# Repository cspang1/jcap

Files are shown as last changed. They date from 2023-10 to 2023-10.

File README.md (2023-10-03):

<h1 align="center">JCAP</h1>

<p align="center"><b>Check out the <a href="https://github.com/cspang1/JCAP/wiki">Project Wiki</a> for the development log</b></p> 
<p align="center"><b>A custom game resource creation software suite <a href="https://github.com/cspang1/jide">is being developed</a> for the inaugural JCAP release!</b></p> 

<hr>

<p>JCAP is a project with the goal of developing a <a href="https://www.mikesarcade.com/cgi-bin/spies.cgi?action=url&type=pinout&page=Jamma.html">JAMMA arcade standard</a> compatible game board using the <a href="https://www.parallax.com/product/p8x32a-q44">Parallax Propeller 1 (P8X32A) microcontroller</a> upon which a user can implement their own custom arcade game, either from scratch or by using the library of graphics, sound, input, and other drivers developed under the project. Ultimately, the project will provide all of the following in such a way that a user has everything they need to implement their own arcade game and have a PCB printed to build it on:</p>

<ul>
  <li>VGA video driver</li>
  <li>Sprite/tile based graphics driver</li>
  <li>PWM sound driver</li>
  <li>Serialized input driver</li>
  <li>Game engine</li>
  <li>Board schematic</li>
  <li>PCB .gerber files</li>
  <li>PCB BOM</li>
</ul>

<p align="center">JCAP Dev PCB</p>

<h1 align="center">Contribution Guidelines</h1>
<p>On the off chance anyone is interested in contributing to JCAP, there are some basic standards which should be ahered to:</p>

<ol>
  <li>Document everything! For code documentation, use existing code (e.g. Dev/Input/Software/input.spin) as an example. PASM should be documented somewhat anal-retentively, line-by-line, with block comments for routines and subroutines. Header comments should follow the same standard established by existing code as well.</li>
  <li>Any discovered problems/concerns/features that you won't be addressing with your current commit need to have an issue created and assigned to the appropriate person(s), tag, milestone, and project. This eliminates the risk of development amnesia. Additionally, when a commit has satisfied an issue, the commit hash should be referenced in the closing comment of the issue.</li>
  <li>Commit messages need to at a minimum broadly describe each change made to the repository. Whether it's fixing a bug, adding a feature, adding a new datasheet, or updating some indentation, one should be able to read the commit message and understand immediately what's been done to the repo.</li>
  <li>Any documents (manuals, datasheets, tutorials) which are critical to your contributions should be placed in their appropriate subdirectories in /Docs. For similarly important generic links, place them in "Useful Links.txt" in /Docs.</li>
</ol>

<p>Pull requests that don't follow these guidelines will be rejected until corrections have been made. While this all may seem like an over-processed waste of time, an auxiliary goal for JCAP is to create a project which maintains the highest possible standards to prevent headache down the road and belay confusion to anyone on the outside looking in.</p>

<h1 align="center">Current Contributors</h1>
<p>The following individuals have contributed to JCAP:</p>

<ul>
  <li>Connor Spangler (cspang1)</li>
  <li>Marko Lukat (konimaru)</li>
</ul>

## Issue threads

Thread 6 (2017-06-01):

Improve 1 microsecond wait subroutine accuracy

cspang1, 2017-06-01:
Currently the wait subroutine exhibits ~.1 us (10%) error.

cspang1, 2017-06-01:
Made unecessary by Issue #9

Closed 2017-06-01.

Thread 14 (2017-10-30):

Perform incrementally misdirected memory access to narrow down tile/color palette VGA issue

cspang1, 2017-10-30:
VGA video dropping entirely with current wip/video/vga vga.spin code as of commit bca37a7fc0f61dbfe6b39d387e2ab001ae3f2507.

Start by trying to directly access color palette and go from there.

cspang1, 2017-10-30:
Issues fixed with commit 9e7ead5c21c01ada62f194a305cbc3deedda6113. Issue was **par** passed to cog is the address of the address of the start of the tile/color resources. So needed to perform _rdlong_ to retrieve the actual addresses of the resources.

Closed 2017-10-30.

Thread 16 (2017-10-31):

Implement Sprite rendering into VGA driver

cspang1, 2017-10-31:
Sprite rendering feature necessary for sprite-based graphics.

cspang1, 2018-01-29:
Being addressed by issue #32

Closed 2018-01-29.

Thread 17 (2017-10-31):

Refactoring of VGA engine set-up for VGA video driver

cspang1, 2017-10-31:
Configuration values are currently hard-coded into VGA driver; need to calculate these values in Hub's Spin and/or Cog's PASM code.

cspang1, 2017-11-02:
Satisfied by commit b4942502ab091ed00d26ba111a279e9dc56a0368

Closed 2017-11-02.

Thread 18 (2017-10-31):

Add content to Propeller 1 wiki page

cspang1, 2017-10-31:
Replace placeholder text with information on Propeller 1 microcontroller, how it works, etc.

Closed 2017-11-02.

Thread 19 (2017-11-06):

Refactor VGA driver code to iteratively assign internal registers from main RAM

cspang1, 2017-11-06:
Currently, all registers in the driver cog which need to be populated with values calculated in the hub are done so one at a time in what's essentially an unrolled loop. Need to determine if there is a way to set them all in a single tight loop.

konimaru, 2017-11-06:
_It's a shame really. Those things have been figured out a long time ago ..._

Check out [this link](http://forums.parallax.com/discussion/comment/1108886/#Comment_1108886), it's a generic loop transferring **a long per hub cycle** in either direction. There is also a counter based version pre-dating this one which - while OK for me - wasn't generally accepted (and sometimes you don't have a spare counter). Anyway, use (one of) them if you want/need speed ...

konimaru, 2017-11-06:
I apologize for the mess Parallax made during forum transition(s) which is the reason I stopped participating.

cspang1, 2017-11-06:
@konimaru Thanks, looks like just the thing I need. Hadn't even gotten around to Googling for a solution yet so thanks for saving me a step! Only thing is that the procedure looks almost as nasty (instruction-wise and visually) as explicitly setting variables, no matter how you do it.

konimaru, 2017-11-06:
Your call. I - obviously - use this in most of my drivers (where applicable). And the setup is only required once.

cspang1, 2017-11-06:
@konimaru True story! I'm definitely riding the assembly-timing learning curve into outer space. I'm actually going to have to do a refactor of my VGA driver to populate a line buffer during the visible porch/sync regions, instead of racing to grab a new tile every time I need it. As-is the driver works fine up to 15 horizontal 16x16 tiles, or 16 horizontal 8x8 tiles. Past that, de-sync.

cspang1, 2017-11-07:
Satisfied by commit a2ff0f2167f0a29744ab3d61e357886df1cfc68d

konimaru, 2017-11-07:
For the record, I just realised you only wanted a one-off load not something repeating (where speed might be important).

cspang1, 2017-11-07:
@konimaru no problem! There's an entirely realistic chance the driver will change in the future to make that necessary, and being aware of the execution-time conscious approach is useful.

Closed 2017-11-07.

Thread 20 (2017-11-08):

Investigate multi-cog vs dedicated PPU video generation approach

cspang1, 2017-11-08:
Current driver has to render faster than it can load the next tile/color at high tile dimensions, and adding the sprite rendering feature will only exacerbate this. The benefits of spreading the rendering of each line over multiple cogs vs having a dedicated PPU with screen buffer need to be investigated.

cspang1, 2017-11-10:
@konimaru I'm definitely interested in discussing what you discuss in this thread if you have the time: http://forums.parallax.com/discussion/126874

konimaru, 2017-11-10:
Ah, that one. I felt a bit odd replying to myself :) Anyway, what are you after?

cspang1, 2017-11-10:
I guess first off, what's the final "verdict" you reached on fully deterministic and synced **waitvid** timing? I see you go through quite a few iterations of solutions, and in your final version you freeze the video hardware before changing **vscl**. Does that have to be done for every change of **vscl** (for example changing for vertical blanking lines and HSync) or just initially?

konimaru, 2017-11-10:
Let me ponder this for a while. This is really **old** stuff and these days I simply _use_ it.

cspang1, 2017-11-10:
@konimaru Haha understood, no problem! I'm working on getting the general structure of this refactor together right now, so no rush!

cspang1, 2017-11-15:
@konimaru I've managed to implement a cog sync method (based on your and Linus's legwork) that's at least as good as it needs to be. I'm not going down the rabbit hole of WHOP methodology at this stage, and likely won't in the future, as the resolutions I'm working with don't require that kind of time-shaving and code obfuscation. I'm still interested in the odd behavior exhibited by the video generation hardware.

As far as this issue goes, I've chosen to go with a multi-cog approach over one requiring a dedicated PPU. My graphics demands simply aren't high enough to warrant a PPU, and at this point I've managed to wrap my head around the multi-cog approach enough to implement it.

cspang1, 2018-01-29:
This paradigm ended up being chosen as the way forward.

Closed 2017-11-15.

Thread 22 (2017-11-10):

Refactor VGA driver to perform interlacing

cspang1, 2017-11-10:
Current line of effort on Issue #20 involves interlacing scanlines via n separate cogs, where each cog renders and displays alternating scanlines e.g. 4 cogs render every fourth line.

cspang1, 2017-11-22:
Satisfied by commit 9f4956a

@konimaru - [success!](https://www.youtube.com/watch?v=sTBAv1NuYT8)

Closed 2017-11-22.

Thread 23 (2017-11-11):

Graphics driver can not be started again after being stopped

cspang1, 2017-11-11:
Calling graphics.start after graphics.stop (or calling graphics.start while driver is already running) results in no video.

konimaru, 2017-11-13:
What is this driver you speak of? The only [**graphics.spin**](https://github.com/cspang1/JCAP/tree/4a9e0d7ffa2518b786a3eae2e0d4fc0a2039d16b/Dev/Game/Software) I could find doesn't even have a **stop** method. And simply calling **start** on that one again will also start another VGA driver underneath (with expected results).

cspang1, 2017-11-13:
@konimaru it's on the feature/video/vga/multicog branch: https://github.com/cspang1/JCAP/tree/feat/video/vga/multicog/Dev/Game/Software

konimaru, 2017-11-13:
This should do the trick:
```
PUB start(graphics_addr_base) : vidstatus | nCogs,i                             ' Function to start VGA driver with pointer to Main RAM variables
    stop                                                                        ' Stop running driver
    repeat i from 0 to numCogs-1                                                ' Loop through cogs
      ifnot cog_[i] := cognew(@vga, graphics_addr_base) + 1                     ' Initialize cog running "vga" routine with reference to start of variable registers
        stop                                                                    ' Stop all cogs if insufficient number available
        abort FALSE                                                             ' Abort returning FALSE
    waitcnt($8000 + cnt)                                                        ' Wait for cogs to finish initializing
    return TRUE                                                                 ' Return TRUE                                        
```
Note the extra **stop** call. This makes sure consecutive **start** calls don't attempt to start thousands of drivers. That said, this wouldn't explain the not-working **stop/start** sequence.

cspang1, 2017-11-13:
@konimaru That definitely did the trick, because in my test code for stopping and starting the driver I don't check if it's already running or not and the input to start/stop is constant, so it just spams start or stop...

`  started := false

  repeat
    if (control_state & 8) AND started
      started := false
      graphics.stop
    elseif (control_state & 4) AND !started
      started := true
      graphics.start`

I code good.

Satisfied by commit 713ed567d48169d914dfebaab7385abe59c118cb

konimaru, 2017-11-14:
Out of curiosity, why did you put this logic into to the application? Isn't the driver itself better suited for this (i.e. keeping state info)?

cspang1, 2017-11-14:
@konimaru Yes it definitely is! I was just testing to make sure the start and stop routines worked, and the easiest way at the time was to control them with button presses. I forsee no real reason I should ever have to stop or restart the video driver unless I implement some sort of software reset for the whole system, so just novelty mixed with making sure everything is tested instead of assumed-working.

konimaru, 2017-11-14:
OK, I thought this is for deployment. Personally I only implement **init** methods. No-one is stopping things anyway so there :)

cspang1, 2017-11-14:
@konimaru That's definitely a cleaner design paradigm haha.

Just a heads up, any branch that's preceded by "wip" is baseline "work in progress" (standard dev, such as for wip/video/vga or wip/video/sound), "feat" is "feature" (a unique dev aspect, such as feat/video/vga/multicog which is focused on refactoring my single-cog driver into a synchronized parallelized one). Other prefixes may be used for things like hotfixes etc. Nothing is merged with master until development on it is considered "complete" (for example, the wip/input branch was merged a while back because I considered the 74HC165 interfacing complete).The idea is that the only production/deployment code will be in master, and everything else is dev.

cspang1, 2017-11-17:
Starting/stopping driver exhibiting strange behavior again.

cspang1, 2017-11-27:
Stopping then starting the driver results in apparently valid sync waveforms, but not video.

cspang1, 2018-01-22:
Made unecessary by dual-Propeller development.

Closed 2018-01-22.

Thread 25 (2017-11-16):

Increase delay between multicog VGA driver cog initializations

cspang1, 2017-11-16:
Currently cogs are launched too rapidly to allow time for the porch sizes to be changed. [Fix identified](https://github.com/cspang1/JCAP/commit/df0fe57e5db38a64c85252066908ad63cf9fe638#commitcomment-25661286) by @konimaru.

cspang1, 2017-11-17:
Satisfied by commit 041e99e710730ddc134a960add3e83da4521f186

Closed 2017-11-17.

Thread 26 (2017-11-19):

Parameterize size of VGA driver scanline buffer(s)

cspang1, 2017-11-19:
[Issue discussed here.](http://forums.parallax.com/discussion/167698/modifying-a-res-statement-before-cog-launch)

cspang1, 2018-01-22:
Made unecessary by dual-Propeller development.

Closed 2018-01-22.

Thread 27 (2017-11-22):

VGA driver tile and color retrieval refactor

konimaru, 2017-11-22:
While probably not terribly important right now I'd suggest a minor change to this:
```
        shl             ti,     tOffset         ' Multiply tile index by size of tile map
        add             ti,     tpbase          ' Increment tile index to correct line
        add             ti,     tpptr           ' Add tile palette pointer to tile index to specify row of tile to be displayed
rdtile  rdlong          tile,   ti              ' Read 16-pixel-wide tile from Main RAM
        shl             ci,     #2              ' Multiply color index by size of color palette
        add             ci,     cpbase          ' Increment color index to correct palette
        rdlong          colors, ci              ' Read tile from Main RAM
movp    mov             0-0,    tile            ' Store tile row to pixel buffer
movc    mov             0-0,    colors          ' Store color palette to color buffer
        add             movp,   incDest         ' Increment tile buffer pointer
        add             movc,   incDest         ' Increment color buffer pointer
```
Here **tile** and **colors** are loaded from hub _then_ transferred to a cog location (2 steps). This could easily be done in a single step e.g.
```
        shl             ti,     tOffset         ' Multiply tile index by size of tile map
        add             ti,     tpbase          ' Increment tile index to correct line
        add             ti,     tpptr           ' Add tile palette pointer to tile index to specify row of tile to be displayed
rdtile
movp    rdlong          0-0,    ti              ' Read 16-pixel-wide tile from Main RAM
        shl             ci,     #2              ' Multiply color index by size of color palette
        add             ci,     cpbase          ' Increment color index to correct palette
movc    rdlong          0-0,    ci              ' Read tile from Main RAM
        add             movp,   incDest         ' Increment tile buffer pointer
        add             movc,   incDest         ' Increment color buffer pointer
```

konimaru, 2017-11-22:
... and to bring this loop a bit (more) in sync with hub window slots:
```
line    rdbyte          ti,     tmptr           ' Read tile index of current map tile
        add             tmptr,  #1              ' Increment tile map pointer to color index
        shl             ti,     tOffset         ' Multiply tile index by size of tile map
        rdbyte          ci,     tmptr           ' Store color index of current map tile
        add             ti,     tpbase          ' Increment tile index to correct line
        add             ti,     tpptr           ' Add tile palette pointer to tile index to specify row of tile to be displayed
rdtile
movp    rdlong          0-0,    ti              ' Read 16-pixel-wide tile from Main RAM
        shl             ci,     #2              ' Multiply color index by size of color palette
        add             ci,     cpbase          ' Increment color index to correct palette
movc    rdlong          0-0,    ci              ' Read tile from Main RAM
        add             movp,   incDest         ' Increment tile buffer pointer
        add             movc,   incDest         ' Increment color buffer pointer
        add             tmptr,  #1              ' Increment tile map pointer to next tile in row
        djnz            tptr,   #line           ' Generate one scanline of data
```

cspang1, 2017-11-22:
@konimaru Great suggestions. A refactor of the tile/color loading to minimize and hub access sync the routine was definitely in order.

cspang1, 2017-11-22:
Satisfied by commit e3f658b90084b0c7b4d8ea538a7e07b9c4d766e0

Closed 2017-11-22.

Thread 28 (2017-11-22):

Refactor multicog VGA driver to re-utilize initialization code as buffer space

cspang1, 2017-11-22:
Chip's high-res VGA driver recycles initialization code to allocate space for the scanline buffer. With a max horizontal tile resolution of 40 tiles, the combined pixel and color buffers for four lines will be **40 * 4 * 2 = 320 longs**. With 496 longs per cog available for instructions and variables, this leaves **496 - 320 = 176 longs available for the VGA driver**. Re-utilizing initialization space, as well as general refactoring of the driver, should be adequate to fit everything.

konimaru, 2017-11-22:
176 longs aren't as much as you think :)

What is the timing like ATM? Could you potentially get away with only two scan lines which need buffering?

cspang1, 2017-11-22:
@konimaru That's the point I'm actually trying to highlight haha; 176 isn't that much space, so re-using initialization code space will help. Right now, the main driver code (sans initialization code) is ~134 longs, and that's without the sprite engine yet.

For 640 x 480 @ 60 Hz, the amount of time over 4 lines that the driver has available to populate the scanline buffer is ~127 microseconds. Best case scanario (all instructions take 4 cycles, so basically ignoring missed jumps and hub memory access) is I can execute 2,540 instructions during this time. Right now @ 40 tiles per scanline I'm at ~2,277 counting all instructions as 4 cycles; so honestly it's probably blowing it as is.

Going down to 2 lines per cog, I would have enough time between display periods to execute 1270... have to finish this in a bit

cspang1, 2017-11-22:
Going down to two lines per cog would rob me of two horizontal sync regions worth of buffer population time, so that's out since I'm already basically at capacity.

This is definitely an area of concern I'll have to address. The thing is though it's only an issue for 40 tile wide screens which is the highest I want to support (most games fall between 30 and 40). The next highest compatible width is 20 but that's honestly too low to make a respectable game from.

cspang1, 2017-11-22:
There are two possible branches to consider at this point:

1. I go from 2 cogs/4 lines each to 4 cogs/1 line each, which would essentially give me 3 entire scan lines worth of time to generate the data for only one (instead of attempting to leverage the horizontal sync areas of 4 lines to find time for 4 lines worth of data).

or...

2. I switch over to a method where there is no interlacing, there is only a cog dedicated to pulling in raw (i.e. already dereferenced from the tile map/palette and colored) video data from Main RAM which is populated by dedicated "render" cogs. This would result in essentially a "backwards" **waitvid**, where each long contains 4 8-bit pixels worth of data and I just print them sequentially. This means a LOT more **waitvids** per line, which means a much lower maximum horizontal video resolution of 256 pixels. Which, to be honest, isn't a deal-breaker as it's still a valid resolution displayable by VGA monitors AND it's actually closer to what classic arcade games displayed via CRT.

For now I'm going to keep working at the current paradigm and leverage some of Chip's high-res VGA driver tricks to see what I can squeeze into the driver in terms of instructions and out in terms of execution time per render.

konimaru, 2017-11-22:
Regarding 2, scanline drivers are available for up to 800 pixels per line (256, 320, 400, 800) so I wouldn't worry to much about it (someone else did all the work already).

cspang1, 2017-11-22:
Interesting, [potatohead over at the Propeller 1 forum made it sound like 256 was _the_ max resolution with that method](http://forums.parallax.com/discussion/comment/1425444/#Comment_1425444)

konimaru, 2017-11-22:
Don't know about that, I just have a 400x300 with overlay in front of me and it's doing fine :)

cspang1, 2017-11-22:
Haha well there you go. Then, honestly, that is probably going to be the next thing I do after I take a crack at wrapping up the current effort. Because, and this is a pretty big deal, when I add in sprites their pixel colors will be **based on the palette of the tile they're in**. This would limit me essentially to monochromatic backgrounds wherever a sprite might need to venture so that I could leave enough colors to define objects so that they don't look like trash haha

cspang1, 2017-12-05:
http://m.wolframalpha.com/input/?i=%2831.777557100298+us+*+4%29+%2F+10.4166667+nanoseconds

cspang1, 2018-01-22:
Made unecessary by dual-Propeller development.

Closed 2018-01-22.

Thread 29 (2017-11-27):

Refactor graphics and VGA interaction to clean up parameters

cspang1, 2017-11-27:
Right now [the VGA driver instantiation from the graphics system](https://github.com/cspang1/JCAP/blob/wip/video/vga/Dev/Game/Software/graphics.spin#L93) is trash; passing completely random parameters like VSync attributes and tile line to scanline ratios. Solution is to pass a pointer to the base of them and perform a **longmove**. Only parameters passed then will be a base pointer to the graphics resources and a base pointer to cog initialization attributes. Consideration needs to be made about exactly what should be calculated in the Graphics vs VGA object. A lot of the calculations will overlap between VGA and RGBS, so it would be poor design to calculate the same attributes separately in the individual video drivers.

Some attributes are used directly by the video driver cog(s) via **rdlong**s, while others are set just before cog instantiation because they're different depending on the cog (e.g. [different vertical porch sizes for interlacing](https://github.com/cspang1/JCAP/blob/wip/video/vga/Dev/Game/Software/vga.spin#L35)). Theoretically you could set ALL attributes in Spin before cog initialization, which would free up a bunch of space currently used to **res** and **long** variables, as well as remove the need to copy memory from the hub to the cog. This however greatly obfuscates the code. Right now this is being done in [a couple places it doesn't need to be](https://github.com/cspang1/JCAP/blob/wip/video/vga/Dev/Game/Software/vga.spin#L102).

Ultimately too much high-level code styling is being considered as the real core of the code is low-level. The added consideration of cog code size is a driving factor.

konimaru, 2017-11-28:
> A lot of the calculations will overlap between VGA and RGBS, so it would be poor design to calculate the same attributes separately in the individual video drivers.

Then again, too much generalisation kills you in the end.

I would also consider whether it's worth doing certain calculations live or **constant** based (compile time). If I were to configure a certain (game) setup I wouldn't expect user input wrt sprite resolution. IOW certain parameters never change (again).

cspang1, 2017-11-28:
It would be the choice between a library of various drivers with different resolutions and tile dimensions and etc. or a single one or two which allows a developer to set those at runtime. Obviously pros and cons of each, but the former has the benefit of reducing the driver memory footprint and being more true to how retro hardware would itself necessarily be constrained.

cspang1, 2018-01-22:
Made unecessary by dual-Propeller development.

Closed 2018-01-22.

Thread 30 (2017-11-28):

[request] compatibility test

konimaru, 2017-11-28:
Seeing that you seem to have P1V hardware available (FPGA), could you please test the following fragment and report the result?
```
                org     0

test            jmpret  $, #setup

' light up an LED here or have some indication that the board is running.

                waitpeq $, #0

                hubop   vscl, #%10000_000
setup           mov     vscl, $-1
                jmp     #$1FF
```
Expected result (based on P1 evidence) is that the **running** indicator should be active.

The P1 has the odd quirk that instructions at address $1FF are cancelled. So in the program above, the REBOOT placed there should be ignored and execution should continue at address 0 falling through to 1 where e.g. an LED is lit followed by an endless **wait**(**peq**).

OTOH, if the REBOOT does fire, the **running** indicator won't be reached.

cspang1, 2017-11-28:
Sure thing! I'll jump on it when I get home.

konimaru, 2017-11-28:
Thanks!

> The P1 has the odd quirk that instructions at address $1FF are cancelled.

Which doesn't mean that it can't be done :)

cspang1, 2017-11-28:
@konimaru So the behavior you described is verified. The following code was used:

```
CON
        _clkmode = xtal1 + pll16x                                               'Standard clock mode * crystal frequency = 80 MHz
        _xinfreq = 5_000_000

PUB main
  cognew(@tester,0)

DAT
              org     0

tester  jmpret          $,      #setup

        or              dira,   Pin_outs        ' Set output pins
        or              outa,   Pin_CP          ' Drive clock pin high

        waitpeq         $,      #0

        hubop           vscl,   #%10000_000
setup   mov             vscl,   $-1
        jmp             #$1FF

Pin_outs      long      |< 0                    ' 74HC165 clock pin bitmask
Pin_CP        long      |< 0                    ' 74HC165 clock pin bitmask
```

I copied the pin-driving lines directly from my 74HC165 driver, and used the logic analyzer test bench for the driver to verify:

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

Pin 0 is driven high, so the **running** indicator was reached.

konimaru, 2017-11-29:
Thanks.

Closed 2017-11-28.

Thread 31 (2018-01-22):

Develop dual-Propeller "display" routine

cspang1, 2018-01-22:
https://github.com/cspang1/JCAP/projects/1#card-6846453

cspang1, 2018-01-27:
Satisfied by commit afe2b99b6fc627876033ce76f14d877c2d639d02

konimaru, 2018-01-29:
Just an observation. You issue **4 pixels** with each **rdlong/waitvid** pair. The worst case time for this sequence is 30 cycles (23+7). At 104MHz (and 25.175MHz pixel clock) that's **7.26 pixels** _you have to_ deliver.

cspang1, 2018-01-29:
I'm not exactly following. I'm rendering 4 pixels per waitvid but they're upscaled via **vscl** to 8 pixels. I've recalculated my **frqa** with 104 MHz and replaced [the old value](https://github.com/cspang1/JCAP/blob/bd81e2bbe446af62310c9bd30a0cfd616fe53224/Dev/Game/Software/vga_display.spin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) with [the new](https://github.com/cspang1/JCAP/blob/wip/dualprop/render/Dev/Game/Software/vga_display.spin#L107).

I've also analyzed the video signal with an oscilloscope and the timings are [almost nanosecond perfect](http://tinyvga.com/vga-timing/640x480@60Hz).

Is there something I'm missing?

konimaru, 2018-01-30:
Sorry, my mistake. I was under the assumption that you go for full 640. With 320 that's perfectly OK. Somehow I missed the **vscl** setup. That said, 320 at 80MHz are possible.

cspang1, 2018-01-30:
Oh no problem haha, thanks for the oversight!

konimaru, 2018-01-30:
I'm getting old :)

Anyway, I'm glad you keep going (was a bit quiet over the holidays).

cspang1, 2018-01-30:
Yeah I was in limbo with the way forward on graphics. I was opposed to a dual-Propeller setup at first because I wasn't certain of its necessity, then I was opposed to running the Prop at 104 MHz because it seemed like a workaround instead of addressing directly the issue of reading and displaying longs back-to-back in time. But at the end of the day, two Props give me an outstanding amount of processing power and time to generate all of the graphics and contituent effects I want, and 104 MHz lets my display code be a lot simpler and gives me even _more_ time to generate graphics. Parallax has tested and approved that frequency, and so far my own testing has confirmed its stability. So now that I've gotten over myself I can push forward haha.

Closed 2018-01-27.

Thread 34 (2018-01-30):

Locks improperly implemented in vga_render due to incorrect addressing

konimaru, 2018-01-30:
**vga_render.spin**
```
  long  var_addr_base_          ' Variable for pointer to base address of Main RAM variables
  byte  cog_sem_                ' Cog semaphore
  long  start_line_             ' Variable for start of cog line rendering
```
This being in a VAR section will actually place **cog_sem_** after **start_line_** (first all **long**s, then all **word**s followed by all **byte**s). In a DAT section the order remains but alignment is forced (3 unused bytes between **cog_sem_** and **start_line_**).

Anyway, I'd simply pick a **long** and that's this problem out of the way. Next issue is that you actually have to read the value, right now you use its assumed address, e.g.
```
  long  var_addr_base_          ' Variable for pointer to base address of Main RAM variables
  long  cog_sem_                ' Cog semaphore
  long  start_line_             ' Variable for start of cog line rendering

        rdlong          clptr,  par             ' Initialize pointer to current scanline
        add             semptr, par             ' Initialize pointer to semaphore
        add             ilptr,  par             ' Initialize pointer to initial scanline
        rdbyte          sem, semptr             ' Get semaphore ID

:lock   lockset         sem wc                  ' Attempt to lock semaphore

semptr  long    4       ' Pointer to location of semaphore in Main RAM
ilptr   long    8       ' Pointer to location of initial scanline in Main RAM

sem     res     1       ' semaphore (or reuse semptr)

```
ATM it works because all cogs have the same value in **semptr** (**par+1**) of which the lowest 3 bits are used as a lock ID (**%-01**, locks don't have to be checked out to be used).

cspang1, 2018-01-30:
Good catch! Wasn't aware of the `VAR` variable organizing behavior. I'll address this when I get home.

cspang1, 2018-01-30:
Satisfied by commit 9198014

konimaru, 2018-01-31:
Your are still using the pointer (where the index is stored) instead of the semaphore index (**lockset** works on a cog register and _doesn't_ do hub access).

cspang1, 2018-01-31:
Thought I'd included that! It's a bugger that the locks work in spite of improper implementation, otherwise without oversight like yours it would literally never be addressed, and any problems that would arise because of it would be incredibly difficult to track down. Thanks!

cspang1, 2018-01-31:
Re-satisfied by 449cb6c2159f40856ba4cd10d3785d4500e19272

Closed 2018-01-31.

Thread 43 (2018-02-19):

Need to further optimize render routine to hit 64-sprite SAT

cspang1, 2018-02-19:
Target size for the sprite attribute table (SAT) is 64 sprites, with a maximum of 8 sprites per scanline.

Right now with the worst case scenario of sprites which have zero transparent pixels: I'm missing the scanline deadline at all 64 sprites and 8 sprites on a line. However, incremental testing has shown that I'm only missing by a factor of a sprite or two per line and ~10 sprites on the screen.

Execution time needs to be shaved off either in the tile rendering section (already unrolled loops) or the sprite visibility check area.

@konimaru I may need your magic on this one. Since I've unrolled the tile parsing loops I don't believe the Counter-B trick we discussed before is applicable.

EDIT: Bumping up the number of rendering cogs from 5 to 6 does the trick and then some (and will give me some time to implement background and (potentially) parallax scrolling). This means I will have to overwrite the interpreter code in cog 0 of the PPU from PASM. In the meantime, I still want to shave off as much time as possible @ 5 cogs.

konimaru, 2018-02-22:
> [@konimaru](https://github.com/konimaru) I may need your magic on this one.

No problem. I'm on holiday right now. I call back :)

Cheers,
Marko

cspang1, 2018-02-22:
@konimaru Sound good; hope you're having a great time!

The code in question is **vga_render.spin** on the **wip/video/sprites** branch.

I think if time can be shaved off anywhere it's in either the [sprite visibility check section](https://github.com/cspang1/JCAP/blob/3dffbcd24f771f3fa689c1434551eaeee7661267/Dev/Game/Software/vga_render.spin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) or the [sprite tile line parsing section](https://github.com/cspang1/JCAP/blob/3dffbcd24f771f3fa689c1434551eaeee7661267/Dev/Game/Software/vga_render.spin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).

Like I said above, bumping up the number of render cogs from 5 to 6 (thus overwriting the SPIN interpreter in Cog 0) lets me hit my goal as well as give me time for some extra effects like fine and parallax scrolling.

So unless you see a really critical optimization, to the tune of hundreds of instructions per line, I think the code is in its almost final state.

Thanks!

konimaru, 2018-03-07:
OK, I'm back to my daily grind. Is that **vga_render.spin** still current, i.e. can I work with/on it?

cspang1, 2018-03-07:
@konimaru welcome back! You'll want to look at HEAD~1 of wip/video/sprites for the last working version of render. In the most recent commit I started working on getting fine sprite scrolling down. Take a look here for specifics on that line of effort: https://forums.parallax.com/discussion/168164/shifting-consecutive-longs

If you look at the most recent commit, all the commented out code will certainly be removed in place of whatever algorithm I implement to populate the buffer w/ fine scrolling.

cspang1, 2018-06-07:
Tentatively satisfied by commit 7de0fe55c306b9192f03856ddd758dfb50977b88

Closed 2018-06-07.

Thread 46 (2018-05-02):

Hardcode graphic resources memory model

cspang1, 2018-05-02:
Currently, the memory model for graphics resources (e.g. tile map, tile palette map, etc.) is arbitrary and each set of elements is addressed individually. This is flexible but introduces unnecessary complexity when implementing inter-propeller communication of the graphics resources.

The solution is to allocate explicit regions of memory for these resources, so the entire memory model as a whole can be transmitted efficiently.

ADDT'L: Modify transfer routine to accept parameterized buffer size, as games will rarely need entire graphics memory.

cspang1, 2018-05-27:
Partially satisfied by commit 343baf7bc1549f1e88ebcfa3ff5d96e30431746f

The "remainder" of each set of graphics resources is hard-coded on the CPU and GPU.

So do I find a way to programatically calculate the unused resource space, or do I modify the TX/RX routines to accept parameterized resource set sizes?

cspang1, 2018-06-08:
Fully satisfied by commit 5ff32c50d31494f47d2a0f4aa01fb3d9e67c59b6

Closed 2018-06-08.

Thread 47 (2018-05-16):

RX cog can miss TX ACK given worst-case hub access times

cspang1, 2018-05-16:
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

Fix is to add at least 3 **nop** instructions [here](https://github.com/cspang1/JCAP/blob/f5575c87971d57fab43bd27f4b189d217942d3e3/Dev/Game/Software/vga_tx.spin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).

konimaru, 2018-05-17:
Shouldn't the delay come **after** the **long** has been sent, or before if you like but definitely not in the middle (between start bit and data)?

cspang1, 2018-05-17:
@konimaru you're right haha, I fat fingered the permalink. **nop**s should be placed [here](https://github.com/cspang1/JCAP/blob/f5575c87971d57fab43bd27f4b189d217942d3e3/Dev/Game/Software/vga_tx.spin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).

cspang1, 2018-05-18:
Satisfied by commit 0e2d445767d28afc13386d538d89271c4bd5f282

Closed 2018-05-18.

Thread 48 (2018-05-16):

TX/RX Routine failing after first full buffer transfer

cspang1, 2018-05-16:
Discussed [here](https://github.com/cspang1/JCAP/commit/f5575c87971d57fab43bd27f4b189d217942d3e3#commitcomment-28964282)

cspang1, 2018-05-18:
Ok @konimaru tell me something: should changing a **dira** bit to 0 (input) not cause that pin to be driven low? Even when there's a pull-down resistor on that pin?

cspang1, 2018-05-18:
Satisfied by commit 0e2d445767d28afc13386d538d89271c4bd5f282

Question still remains of **dira** behavior.

cspang1, 2018-05-18:
@konimaru my entire project is now running on 100% actual hardware: two P8X32As w/ support circuitry et. EEPROMs. I'm using a 10K pull down resistor on the data line. Does this sounds like a fault uC IC then?

konimaru, 2018-05-18:
Let me try this at home. How long is your cable?

Can you easily change pins?

cspang1, 2018-05-18:
@konimaru cable is a few inches; the two uCs are on the same standard breadboard (breadboards being notorious for signal noise and ground plane sinking, maybe a source of the problem itself?)

Pins are easily changed in both TX and RX: TX by changing the variable in the vga_tx CON section, and RX by changing the variable at the bottom of the vga_rx PASM section. I should probably standardize that, eh?

I've tried changing pins during debugging to no avail.

I don't say it enough but thanks again for lending your time, effort and experience to my little hobby project :)

konimaru, 2018-05-18:
So effectively the sequence (plus pull-down)
```
or      outa, TxPin
or      dira, TxPin
andn    dira, TxPin
```
is all I need to see if it works or not?

cspang1, 2018-05-18:
@konimaru yep that should be the most trivial case

cspang1, 2018-05-18:
@konimaru I completely agree! I can do a sanity check when I get home, but I'm 99.9% certain one end of a 10K resistor is attached to pin 0, and the other end is attached to ground. Maybe I'm getting some strange impedence effect, and I need to lower the pull down resistor value?

konimaru, 2018-05-19:
Just checked on my trusty demoboard with a 10K pulldown. One cog just samples a pin (3) and copies its state to an LED pin (23). With the sequence in question (even in Spin) it stays high after the pin is set floating (no pulldown) for a while. With the pulldown in place I never see a blip on the LED.

konimaru, 2018-05-20:
At PASM level I get an expected 4 cycles with forced **outa** toggling. Switching off **dira** instead clocks in with 23 cycles (10K pull-down). So maybe the 10K are a bit high for this purpose.
```
CON
  _clkmode = XTAL1|PLL16X
  _xinfreq = 5_000_000

CON
  PIN = 3

VAR
  long  stack[32]

PUB null

  cognew(@main, 0)
  cognew(link, @stack{0})
{
  waitcnt(clkfreq + cnt)

  outa[PIN] := 1
  dira[PIN] := 0
}
  waitpne(0, 0, 0)

PRI link

  ctra := constant(%0_11010_000 << 23 | PIN)            ' LOGIC A
  frqa := 1

  waitpeq(%1000, %1000, 0)
  waitpne(%1000, %1000, 0)

  dira[23..16]~~
  outa[23..16] := phsa <# 255

  waitpne(0, 0, 0)

DAT             org     0

main            or      dira, #|< PIN

                rdlong  cnt, #0
                add     cnt, cnt
                waitcnt cnt, #0

                or      outa, main
'               mov     outa, #0                        '  4 cycles
                mov     dira, #0                        ' 23 cycles (10K pull-down)

                waitpeq $, #0

                fit
        
DAT
```

cspang1, 2018-05-20:
@konimaru Interesting; I was under the impression that 10K was standard across the board as a pull-down value for P8X pins. I'm thinking this may also be the cause of issue #49. Thanks for the legwork!

konimaru, 2018-05-20:
I'd leave the pull-down in (just to have a base line) and do a forced **outa**.

cspang1, 2018-05-21:
@konimaru Yeah that's going to have to be the solution. I cut the resistor value in half and was _still_ not seeing the appropriate behavior. I'm starting to wonder whether this is a breadboard impedance issue, or something caused by connecting the two props. Because, logically, the only two explanations are:

1. Vss is floating high relative to Vdd, causing the appropriate differential to not be met
2. There is either low impedance on the Prop-Prop connection causing cross-talk that bypasses the pull-down or somehow the TX Prop is still driving a logic low at the critical moment

cspang1, 2018-05-22:
@konimaru scratch all of that I'm picking up what you're putting down now. So the time constant for the circuit created by the interconnected prop is defined by a 20 pF mutual capacitance. Just based on the 23 sysclock count you identified, I need to drop the resistor down to 1K (minimum of 1.4 to be precise).

Regardless, I'm going to keep the explicit driver instructions because a digital margin of error is better than an analogue margin of error.

Closed 2018-05-18.

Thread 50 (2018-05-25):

Create TX routine init watchdog

cspang1, 2018-05-25:
Currently there's no system in place to ensure the RX routine is listening before the TX routine begins a connection attempt. Need to add a watchdog system in the **start** method.

cspang1, 2018-05-26:
Satisfied by commit 79802549f4bfa5185ee02990ab42d47b009ff190

Solution (and fix for issue #49) was to ensure the RX routine was flushed back to the start of waiting for a buffer transfer to initiate. This required aligning the flush and TX initiations to VSYNC, something that was going to ultimately be done to ensure buffer modifications wouldn't happen mid-transfer/display.

Closed 2018-05-26.

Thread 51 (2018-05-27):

Horizontal sprite tearing occurring on first row of tiles

cspang1, 2018-05-27:
Carry-over from issue #45.

~~Tearing occurs only around scanline 5/6, and behaves strangely:~~
~~Scanline 5 will have its left two pixels cut off~~
~~Scanline 6 will be shifted left one pixel~~

~~Can actually cause video dropout and Propeller _**restart**_ by rapidly moving the sprite up and down past this scanline!~~

More details forthcoming.

cspang1, 2018-06-06:
Issue NOT triggering display failure; parasitic inductance in the breadboard setup was causing that sporadically.

Issue has with 100% confidence been identified as resulting due to the first several render lines using data from the previous frame, i.e. previous graphics resource buffer transfer.

Devoting more cogs to rendering results in more scanlines being affected, e.g. @ 5 render cogs the first 6 scanlines are behind but @ 3 render cogs the first 4 scanlines are behind.

Solution unclear yet.

cspang1, 2018-06-06:
Satisfied by commit bccb7501

Closed 2018-06-06.

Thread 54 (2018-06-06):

Research implementing 8-bit color w/ separate VSYNC/HSYNC pins

cspang1, 2018-06-06:
Might be impossible due to already-tight _vga_display_ routine timing, but worth the four-fold increase in color fidelity.

konimaru, 2018-06-07:
Been there, done that, works :)

cspang1, 2018-06-07:
@konimaru Yep someone mentioned your name on the forum when discussing it!

Without looking at your implementation, I'm wondering how you were able to toggle the HSync/VSync outputs deterministically.

e.g. **waitvid** will finish displaying the visible region of the scanline, then transition to the horizontal front porch. Pulling down the HSync pin via **andn _outa_, HSPin**  even the instruction immediately after the HSync region **waitvid** was executed would still introduce a data path's amount of lag into the toggling of the pin.

konimaru, 2018-06-07:
That's not quite how it works. While I do the visible stuff the sync lines are kept idle by **outa**. Basically, after the last pixel I register the hsync stuff normally with a **waitvid** (so timing is exact) and only then I switch byte lanes in **vcfg** to have the sync pulse on the correct pins. Just before the front porch runs out I switch lanes again and **outa** takes over again.

cspang1, 2018-06-07:
@konimaru ah I see, that makes perfect sense, thanks!

I can see how active-high sync signals would be trivial to implement with pull-down resistors, however my sync signals are active-low.

konimaru, 2018-06-08:
First, apologies, I got front/back porch mixed up (I was under the impression it's in **front** of the video signal when in fact it's in relation to the sync pulse).

Anyway, no messing around with **dira** here.
- **dira** covers 8bit video and 2bit sync from the start and is never touched again
- **outa** is set (initially) to idle state (high) in the sync pin location
- video line is displayed
- hsync **waitvid** is issued (front+sync+back)
- immediately after that **vcfg** is updated (pin group) then **outa** is cleared (no interference)
- now we have to calculate a point in time when the back porch becomes active (sync lines high again)
- at this point **outa** goes back to idle (take over) followed by a **vcfg** pin group switch for the next scan line

The last point has to be carefully adjusted because we don't want to bleed the (now high) idle state into the colour group before its time. Admittedly that is the case in my driver (for a few ns) but I like stuff to be clean.

konimaru, 2018-06-08:
FWIW, the bleeding can be avoided with an exotic sync pattern, i.e. keep low until switchover (**vcfg**) then high before release (**outa**) and reverse that before going back to visible video.

cspang1, 2018-06-08:
@konimaru No problem! If you google "vga porch timing" you'll see it BOTH ways all over the place; makes have a technical discussion about it without a reference much more difficult.

I was under the impression that **vcfg**, like **vscl**, is latched at the moment of the next **waitvid** execution.

konimaru, 2018-06-08:
In my experience **vcfg** takes immediate effect :) There was a QuickStart extension board for PropellerBASIC which had a 256colour mode. It wouldn't have worked since I use a single **waitvid** for hsync.

cspang1, 2018-06-08:
@konimaru Interesting, thanks! Really wish that kind of info was in the Prop datasheet!

I took a crack at an "exotic" sync pattern w/o color bleeding. See anything obviously wrong?

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

cspang1, 2018-06-11:
@konimaru No problem, being on opposite sides of the world has its inconveniences haha! Good call on the back porch as well; thinking about it this morning and I felt I was missing something.

For this project, transparency and maintainability of operation are definitely high priority, as a goal is for anyone to be able to come behind and modify the drivers if a game calls for it.

Closed 2018-06-11.

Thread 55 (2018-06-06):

Update wiki video implementation

cspang1, 2018-06-06:
Need to elaborate on implementation of data transfer and addressing resultant bugs (#51 ) to [video part #4](https://github.com/cspang1/JCAP/wiki/JCAP-Log-%239:-Video-Part-4).

cspang1, 2018-06-07:
+ decoupling capacitors

Closed 2018-06-18.

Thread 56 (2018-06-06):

Update datasheets and schematics for current circuit

cspang1, 2018-06-06:
74HC165
LD33CV
24LC256
etc.

cspang1, 2018-06-15:
https://easyeda.com/editor

cspang1, 2018-06-15:
https://electronics.stackexchange.com/questions/367797/resistor-dac-and-buffer-for-vga-output/367806#367806

cspang1, 2018-06-16:
@konimaru
I'm upgrading my VGA DAC to 8 bits, and found [this stackoverflow answer going into some good implementation detail](https://electronics.stackexchange.com/questions/367797/resistor-dac-and-buffer-for-vga-output/367806#367806).

But at the bottom of the answer, in the "edit", he says that "you don't want 400 mV at the input of the other side of the transmission line. You want 200 mV there. The 75 Ω series termination resistance and the 75 Ω parallel termination resistance forms a voltage divider with a ratio of 2:1. So it will expect half the voltage, not the entire voltage."

I'm not seeing at all how having 1/2 your target voltage at DAC output is supposed to be appropriate, as the divider actually has a 1/2:1 ratio. Thoughts?

cspang1, 2018-06-16:
https://easyeda.com/cspang1/JCAP

cspang1, 2018-06-18:
Satisfied by commit f706d67539811e058f30af8e1f3da350c5230424

Closed 2018-06-18.

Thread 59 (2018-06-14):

Investigate replacing data signal pin w/ memory R/W

cspang1, 2018-06-14:
Currently, GPIO pin is used to signal render cogs that graphics data is ready for generating scanline data.

Replacing with a memory-based solution will reduce signal noise on the board and frees up a pin.

cspang1, 2018-06-15:
Satisfied by commit f41f9a5fd7fb1d70b1be4e00e01165c4ed0a1ac8

Closed 2018-06-15.

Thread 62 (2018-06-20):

Decouple TX/RX From VSYNC

cspang1, 2018-06-20:
Greatly over-complicates implementing anything time-sensitive.

cspang1, 2018-06-21:
@konimaru I'm strongly considering using [your high speed serial routine](http://forums.parallax.com/discussion/110325/fyi-single-wire-high-speed-serial-link-updated-20110514) depending on its transmission speed. I'm getting ~13 Mbps @ 104 MHz system clock currently.

cspang1, 2018-06-21:
@konimaru makes sense, thanks!

Potentially stupid question: how does the `wrlong  par, par` clear the `par` register to zero? Wouldn't `wrlong` take the value in `par` (size:addr) and just store it into whatever register is created by the combination of size:addr?

konimaru, 2018-06-22:
Yes and yes. These days I use `wrlong zero, par` with `zero` being a constant with value `$1F0`.

cspang1, 2018-06-25:
Alright @konimaru, I'm officially at a loss. [Calling the assembly via `cognew` works perfectly](https://github.com/cspang1/JCAP/blob/bug/txrx/refactor/Dev/Software/cpu.spin#L48); no issues.

But if I comment that out, and uncomment the line above which invokes [the exact same assembly except via an object](https://github.com/cspang1/JCAP/blob/bug/txrx/refactor/Dev/Software/tx.spin), the routine does nothing and I cannot get any debugging done deterministically.

I can only imagine it has _something_ to do with the address being passed it, but I can't fathom what it is. Thoughts?

konimaru, 2018-06-26:
[This line](https://github.com/cspang1/JCAP/blob/b5546437028c531eaaeb0d20672d0f42e10a7586/Dev/Software/tx.spin#L54) should read `:primary rdlong buff, tx_addr`.

cspang1, 2018-06-26:
*screams in pain internally*

cspang1, 2018-06-27:
Satisfied by commit 95ec6d062ec8657aaefdfb8121d3011ebde27ef6

Thanks again @konimaru!

Closed 2018-06-27.

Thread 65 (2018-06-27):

Integrate stereo/mono pre-amp and RGBS circuits w/ schematics

cspang1, 2018-06-27:
Audio circuit: http://www.pinballzone.com/forums/mvsjammaswitchbo6.jpg
Audio discussion: https://forums.arcade-museum.com/showthread.php?t=431021

Sync circuit: https://klovimg.com/images/2018/06/27/SYNCCOMB.gif
Sync discussion:  https://forums.arcade-museum.com/showthread.php?p=3827307#post3827307

cspang1, 2018-07-02:
Coin counter - 2 transistors + passives
Audio amp - amp + passives
Sync - XOR IC + passives
Input - SIP resistors

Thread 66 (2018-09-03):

Fix intermittent start-up video desync

cspang1, 2018-09-03:
Occasionally, start-up will be desynced. Likely a race condition with a main memory access; need to deterministically time sync.

cspang1, 2019-03-22:
Per #63...

Relatively certain what's happening is that the worst-case scenario for the RX cog results in long count being loaded on Cog 0's side after the TX cog has started firing.

Likeliest solution is to pass `constant(GFX_BUFFER_SIZE << 16) | @gfx_buff` to the RX Cog and let it proceed to `waitpeq`ing internally.

cspang1, 2019-03-22:
May have fixed w/ commit 45524524218d5a4839a7c6a34e8fc2a364d77e4e, pending verification...

cspang1, 2019-03-24:
Looks like it may actually be caused by the write on the TX side to the `trans` address too soon...

cspang1, 2019-05-13:
Next debug step is to hardcode some long waits in critical sections to try and force the behavior.

cspang1, 2019-05-14:
This is 100% happening when TX is running BEFORE RX is, 0% vice versa - narrowing down cause via scratchpad and deterministic timing.

konimaru, 2019-05-14:
Couldn't you do something simple like a start-up handshake and then use said line(s) for normal transfer?

cspang1, 2019-05-14:
That's actually what I'm already doing! I'm using the vertical sync (`VS`) and TX/RX (`X`) line as a two-way handshake which accounts for either Prop starting up first: the GPU's RX cog waits for `VS` to go high, while the CPU's RX cog drives `V`S high and then immediately waits for `X` to go high.

So if the CPU starts up first, it drives `VS` high and it waits for `X` to be driven high by the GPU. When the GPU eventually starts up, its `waitpeq` will immediately detect `VS` is high, and proceed to immediately drive `X` high, notifying the CPU to proceed as well.

If the GPU starts up first, it immediately starts waiting for `VS` to be high. When the CPU eventually starts up, it will drive `VS` high which causes the GPU to immediately drive `X` high, which notifies the CPU to proceed.

This paradigm works the majority of the time, with video starting and displaying seamlessly when both uCs are started at (ostensibly) the same time.

The problem is that, occasionally and without any apparent deterministic pattern, the transfer will be very slightly desynced at startup - colors and patterns flashing around in incorrect places, but the basic elements are definitely there.

What is almost certainly happening, and I have a test planned for this evening to verify, is that the transfer itself is desyncing - what the RX cog thinks is the "start" of the data stream is actually within the stream elsewhere, off by some yet-unknown number of bits, bytes, words, or longs.

What I've been able to determine for certain so far is that this behavior *only* happens when the CPU is running *before* the GPU (TX cog running before RX cog). Even with this startup order enforced to purposely trigger the desync, it still doesn't happen every time (maybe 1/3rd of the time).

So now I'm in a position of trying to determine if this is:
1. A hardware instead of software problem - the breadboarded nature of the circuit is causing errant behavior in the transfer (unlikely, as it would then happen regardless of which uC started up first) or maybe the individual clocks of the uCs are aligning or misaligning or mistiming in just the right way to cause an off-by-one-cycle error (again, if so then why wouldn't this happen regardess of which uC started up first)
2. An edge case, where a worst-case hub access timing is causing the desync somehow (my original thoughts, as the difference between 8 and 23 execution cycles would fit like a glove for an occasional symptom like this - but after plotting out the worst-case execution times down to the clock cycle in Excel, I don't see anywhere that this would be happening)
3. Something I haven't considered yet, which is where I'm sitting now

The fact that I've narrowed it down to only happening when TX precedes RX should be a big hint, but the random nature even then of the behavior is eating my chili. My most recent attempt at rooting out the cause was trying to force it to happen 100% of the time, adding delays between critical sections, but that didn't bare any fruit.

[Here's the TX code with the handshake starting at line 86](https://github.com/cspang1/JCAP/blob/bugfix/video/startup/Dev/Software/tx.spin#L86), and [here's the RX code with the handshake starting at line 78](https://github.com/cspang1/JCAP/blob/bugfix/video/startup/Dev/Software/rx.spin#L78)

Somethign I may do tonight is remove the handshake code altogether, force TX to start before RX, and preclude that the handshake itself is the problem. If I can rule that out entirely, then that's another data point.

If you have any thoughts, they would be greatly appreciated. This issue has knocked me off of development for the past several months.

cspang1, 2019-05-14:
A new data point: forcing the RX cog to only accept a single transmission (followed by an infinite `jmp $`) shows me that the behavior is evident from the very first frame of data transmitted. I'm replacing one of the GPU rendering cogs with a serial transmission COG to sample the data that is in the video buffer to see whether the stored video data received from the CPU is errant.

cspang1, 2019-05-14:
Ok we're getting down to it now:

11111111_00001111_11000011_00000011 <--- GOOD GFX DATA
11111111_10001111_11100011_10000011 <--- BAD GFX DATA
11111111_00000111_11000001_00000001 <--- BAD GFX DATA
01111111_10001111_11000011_00000011 <--- BAD GFX DATA

These are all samples of the very first `long` of the GFX buffer on the GPU. All of these values and more are being seen, when only the first is stored in that memory during nominal operation. The only obvious pattern here is that the only bits that are being corrupted are those which are adjacent to a bit toggle (i.e. the preceding or following bit is different than the current one).

This therefore truly looks like the RX prop is somehow becoming de-synced despite the deterministic timing, and trying to read data off the wire at the instant the bits are changing; sometimes it gets the correct data, other times it gets the wrong next one.

Still digging for the cause.

cspang1, 2019-05-15:
Removing the handshake PASM entirely causes the problem to disappear. I'd like to say that this finally narrows the problem down to the ~10 lines of code which defines the handshake routine, but we'll see. Again, I've plotted out every instruction for the best and worst case timing scenarios down to the individual clock cycle and could not find anything that would cause this problem.

cspang1, 2019-05-15:
Finally narrowed down to the problem to, surprisingly enough, the TX side of the house. Only when the handshake code is present in the TX routine (with the RX-side handshake moved out to SPIN) does the problem occur. I'm sure there's a logical explanation regarding timings and whatnot, but for now the problem has been solved by moving all handshake code out to SPIN in the `main` functions. The next iteration will be to move the handshakes into the individual TX and RX module functions.

This issue has been (initially) satisfied by commit f8b7b4c3115bc056ab05216b7fd197fa726fc405

Closed 2019-05-15.

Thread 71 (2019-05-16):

Implement sprite sizing

cspang1, 2019-05-16:
Should be able to render sprites @ 8x8, 16x16, and maybe even 32x32 sizes, along with permutations of these sizes.

cspang1, 2019-05-30:
For wide horizontal sprites, will need to loop back around to palette load. Will also need to increase buffer overflow space by another 2 longs to compensate.

konimaru, 2019-05-30:
A bit OT: what’s the worst case timing for rendering one line? Do you have any numbers?

cspang1, 2019-05-30:
The worst case timing currently results when you have the maximum number of sprites per scanline end-to-end w/ no transparent pixels (just an 8x8 pixel completely filled square). That results in the maximum number of rendering instructions per scanline. The timing for this is obviously dependant on what the maximum sprites per scanline is set to. After last week's shakedown of the render code, I was able to hit 20+ sprites before artifacting started.

The upper bound though is easy to calculate: 6 render cogs @ 2 visible lines displayed per rendered one (2x upscaling), 31.778 us per scanline (by the VGA standard) - so 63.555 us per upscaled scanline, times 6   for the cogs sharing the load, and we get 381.33 us to render a scanline.

cspang1, 2019-05-30:
Need to loop back to [this line](https://github.com/cspang1/JCAP/blob/c272e3687cb5802c3a4eea1c16926adb485fc3b0/Dev/Software/vga_render.spin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) w/ an address increment. Will also potentially need to adjust offset/wrapping logic...

cspang1, 2019-05-31:
@konimaru want your opinion on this: by implementing sprite sizing, you're definitely saving cycles on the CPU-side of the house (only need to update on SAT entry for a 16x16 sprite instead of 4), as well as some on the GPU side (can skip some position checking instructions).

But, it makes the actual maximum sprites per scanline difficult to pin-down: you can probably fit 20+ 8x8 sprites on a scanline, or 10+ 16x16 sprites, but mixing the two or mixing in 16x8 and 8x16 makes dozens of permutations. My pseudo-OCD doesn't like this uncertainty, but the reduction in headache on the game dev side by not having to deal with every single 8x8 sprite individually really gives the feature some merit. Thoughts?

konimaru, 2019-06-01:
I see what you mean ... and you ask me with blood type A :)

That being said, if it's easy and has certain benefits (big sprites are cool) I'd go for it. As for **measuring** this, not sure if this holds true: Is it guaranteed that with a given N 8x8 sprites you can get effectively more of them per scanline when some of them are combined e.g. M 16x16 + P 8x8 (2*M+P>N)? If that's the case I'd simply state that you could have N base sprites and may get _more_ etc if and when. OTOH I wouldn't necessarily squeeze that into a formula.

If the above isn't true for all cases then we'd have to think of something else, maybe some form of optimistic limit (e.g. not 20 but just 16 sprites/scanline). I'll keep this issue in mind and think about it a bit more.

cspang1, 2019-06-02:
Thanks for the input - I'm definitely leaning heavily towards implementing them and letting the uncertainty be. Working out the implementation details has also revealed some further overall refinement, such as extending the scanline buffer at the beginning the same way I did to the end, allowing for rendering in non-displayed space without having to deal with calculating offsets for partially on-screen sprites.

cspang1, 2019-06-03:
Thinking with extended buffer method, will need index to reset to buffer origin `SprSzX` pixels "early", i.e. reduce `maxHor` by `SprSzX` prior to `cmpsub`. Remove shifting and offset logic, just use `cmpsub` result as origin for rendering sprite.

cspang1, 2019-06-12:
Life getting in the way of finally implementing this...

W/ buffer added to beginning, will need to compensate for 8-px wide sprites needing to start rendering in second half of extra buffer space.

cspang1, 2019-10-23:
Moved to a new state for a new job, finally everything's settled down enough to start working on this again...
<a href="https://imgur.com/sAlvhor">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</a>

konimaru, 2019-10-23:
Welcome back and best wishes!

cspang1, 2019-10-24:
Managed to implement a basic wide sprite, but horizontal/vertical/multidirectional mirroring is still left. Beginning to get a nagging suspicion that fully implementing this will take more of a toll on the max sprites per line metric than it's worth.

cspang1, 2019-10-25:
[Completely scrapped the janky horizontal wrapping offset calculation nonsense](https://github.com/cspang1/JCAP/commit/148e57ac9b6455805b2dbd23136f70c57316b043) and opted to simply extend the scanline buffer to the left of the screen and
1. Use 16 pixels left of screen for sprites sliding into the frame, and
2. Use sprite x position '0' as an invisible location, providing the benefit of an easy coordinate to hide unused sprites in the SAT

Adds only 4 longs of cog memory overhead for the additional buffer space, but many more removed (as well as resulting execution cycles) in removing the instructions for the offset calculation voodoo.

With this improvement, sprite sizing is looking (tentatively) much more reasonable.

cspang1, 2019-10-27:
Hard part done w/ horizontal wide + mirrored sprites successfully implemented via 15f7b4be0233b100009cebb433986ab3771f7a5c

cspang1, 2019-10-27:
Critical code section for refactoring:

```
sprites ' Load sprite attributes
        rdlong          curmt,  tmindx      ' Load sprite attributes from Main RAM
        mov             temp,   curmt       ' Copy sprite attributes to temp variable
        shr             temp,   #7          ' Shift vertical position to LSB
        and             temp,   #255 wz     ' Mask out vertical position, checking invisibility
        cmp             maxVVis, temp wc    ' Check sprite upper bound
        if_be jmp       #:skip              ' Skip sprite if invisible or out of bounds
        mov             spypos, temp        ' Store sprite vertical position

        ' Check if sprite is on scanline vertically
        add             temp,   #system#SPR_SZ_S-1          ' Calculate sprite vertical position upper bound
        cmp             temp,   cursl wc                    ' Check sprite upper bound
        if_nc cmp       cursl,  spypos wc                   ' Check sprite lower bound
        if_nc jmp       #:cont                              ' Check sprite horizontally within scanline
        cmpsub          temp,   #system#MAX_SPR_VER_POS wc  ' Force wrap (carry if wrapped)
        if_c  cmpx      cursl,  temp wc                     ' Re-check bounds
        if_nc jmp       #:skip                              ' Skip sprite

        ' Calculate vertical sprite pixel palette offset
        mov             spyoff, #system#SPR_SZ_S-1  ' Copy sprite vertical size to sprite vertical offset
        sub             temp,   cursl               ' Subtract current scanline from sprite lower bound
        sub             spyoff, temp                ' Subtract vertical sprite position from vertical sprite size
:cont   if_nc mov       spyoff, cursl               ' Store current scanline into sprite offset
        if_nc sub       spyoff, spypos              ' Subtract vertical sprite position from sprite offset

        ' Check if sprite is within scanline horizontally
        mov             spxpos, curmt       ' Copy sprite attributes to temp variable
        shr             spxpos, #15         ' Shift horizontal position to LSB
        and             spxpos, #511 wz     ' Mask out horizontal position, checking invisivility
        cmp             maxHVis, spxpos wc  ' Check sprite upper bound
        if_be jmp       #:skip              ' Skip sprite if invisible or out of bounds
        test            curmt,  #2 wc       ' Check if sprite is wide
        if_c mov        widesp, #2          ' If so increment wide sprite index
        if_c mov        wmmod,  #8          ' And set sprite position modifier
        if_nc mov       widesp, #1          ' Otherwise only render one sprite palette line

        ' Retrieve sprite pixel palette line
        mov             temp,   curmt               ' Copy sprite attributes to temp variable
        shr             temp,   #24                 ' Align sprite pixel palette attribute to LSB
        shl             temp,   #5                  ' Calculate sprite pixel palette Main RAM location offset
        add             temp,   spptr               ' Calculate sprite pixel palette Main RAM base location
        test            curmt,  #8 wz               ' Check sprite mirrored vertically
        if_nz subs      spyoff, #system#SPR_SZ_S-1  ' If so calculate inverted offset...
        if_nz abs       spyoff, spyoff              ' And calculate final absolute offset
        shl             spyoff, #2                  ' Calculate vertical sprite pixel palette offset
        add             temp,   spyoff              ' Calculate final sprite pixel palette Main RAM location
        rdlong          curpt,  temp                ' Load sprite pixel palette line from Main RAM
```

cspang1, 2019-10-28:
Satisfied by commit 2708506cee6fffaded65836cb1a269189be6707c!

Closed 2019-10-28.

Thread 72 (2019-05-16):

Implement fine pixel tile scrolling

cspang1, 2019-05-16:
Goal: ability to scroll background tiles smoothly horizontally, i.e. pixel-by-pixel. Could have system to allow for multiple different regions of different scroll rates. Primary goal however is to simply achieve fine scrolling.

Scrolling cannot be done on the CPU side - there's no way to de-conflict tile color palettes. So any fine scrolling must be done on the GPU side.

Horizontal scrolling will require some work - rendering tiles not on their boundaries results in needing to process an additional tile for each **long** of stored video data.

Planning out in scratchpad.

cspang1, 2019-05-16:
Will need horizontal and vertical "position" tracking variables passed from CPU to control scrolling.

Hard-incremented on [this line](https://github.com/cspang1/JCAP/blob/master/Dev/Software/vga_render.spin#L342), as we will need the data for an extra tile during scrolling.

We instantiate a render cog internal tracker for which horizontal pixel we're rendering (**curpx**).

So the routine should operate as follows for horizontal fine scrolling (starting at the very beginning of a scanline):
1. We instantiate a variable **curpx** to track which physical pixel of the scanline we're currently rendering
2. We retrieve a variable **h_pos** from the graphics resources to determine what pixel of the tile map is aligned with the left side of our screen
3. We determine what our initial tile is by performing **floor(h_pos/4) = floor(5/4) = 1**, and load that tile's **word** to be processed.
4. We then determine what specific pixel from the tile palette we're processing by performing **h_pos%4**, and load that pixel for rendering
5. When we proceed to the next pixel, we first check that we've entered a new tile by checking whether **curpx%4==0**. If so, we load the new tile and continue rendering pixels
6. We repeat steps 4 and 5 until we have a **long** worth of graphics data to store, with the option of either breaking out of the process when we hit that or letting the buffer overflow to save cycles on all of the checks that would be performed

cspang1, 2019-05-17:
Satisfied by 02e3e464f522312893bc89187d3401382fe07512

Closed 2019-05-17.

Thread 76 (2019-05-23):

Determine EEPROM Writing Solution

cspang1, 2019-05-23:
This is looking somewhat further down the proverbial development road.

I will be using a [1Mbit SPI EEPROM](https://www.mouser.com/ProductDetail/Microchip-Technology/25LC1024-I-P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) for static game resource storage (tile map, tile/sprite pixel palettes, tile/sprite color palettes), which would allow for ~50 full tile maps worth of canvas. This data will be loaded into a [1Mbit SPI SRAM](https://www.microchip.com/datasheet/23LC1024) at system instantiation.

The question is: what's a reasonable way to load 128K worth of data into the EEPROM, when the Propeller can only handle 32K at programming time. Should an in-circuit programmer be used? Should some shenanigans be implemented to load the data piecemeal via the Propeller? Should the data be sent serially to the Prop via the Prop Plug and stored one at a time?

I'm certain there is a best practice well accepted solution to this, but nothing is really popping out in my searches.

Ideally the solution would be one-click, as during game development the graphics resources would be constantly updated and tested, so if there's a solution that wouldn't require overwriting the boot EEPROM of the Propeller (so as not to overwrite the CPU code itself, necessitating a re-load) or even better wouldn't require the Prop at all, it would be ideal.

cspang1, 2019-05-23:
[Looks like Macca was investigating this exact same problem](http://forums.parallax.com/discussion/162274/large-read-only-data-tables), but doesn't seem to really elaborate on his solution - plus it looks like he's using a C compiled solution.

konimaru, 2019-05-23:
There is the Hydra-Asset-Manager (HAM). It needs some tweaking (the back end on the P1) but worked fine for me in the past. I believe up to 128MB was possible.

[HAM_1_09.zip](https://github.com/cspang1/JCAP/files/3213584/HAM_1_09.zip)

cspang1, 2019-05-23:
Outstanding - any elaboration for "tweaks on the back end"?

konimaru, 2019-05-23:
The original backend used the TV driver + the Graphics object. I commented that out. I believe you have the tweaked version already in that archive.

cspang1, 2019-05-23:
Oh nice. I'm thinking though... the Propeller's boot EEPROM is I2C, but the ones I'm attempting to write to are SPI - so I'll certainly have to replace the I2C logic with SPI logic, as well as change the GPIO ports used.

konimaru, 2019-05-23:
Ah, yes. I forgot but it shouldn't be too much effort.

cspang1, 2019-05-23:
Nah, especially with a great deal of SPI logic already available in the Propeller library.

cspang1, 2019-05-25:
Will be satisfied w/ HAM.

Closed 2019-05-25.

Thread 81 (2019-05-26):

Implement parallax scrolling

cspang1, 2019-05-26:
Can either implement via NES-style "sprite marker" (last scanline of sprite 0 sets a flag), or use a more robust method by passing _N_ scanline indexes representing where change in scrolling takes place.

cspang1, 2019-05-28:
Or just read from a 30-long array containing individual horizontal positions for each row of tiles. Would be as simple as using the current scanline as the index for the array. Would introduce only a few instructions of overhead on the render side:

_cpu/gpu:_
```
parallax_arr byte 0[30]
```
_vga_render:_
```
plxptr = parallax_arr_base + cursl
rdlong horpos, plxptr
etc.
```

konimaru, 2019-05-28:
After last weeks session you should have lots of space/time :)

Why 30 in particular?

cspang1, 2019-05-28:
Haha thanks to you definitely. Screen is 30 tiles tall, so you could have every row of tiles parallaxing at different speeds. Doing it per individual scanline would also be more robust, allowing for the ability to create some really cool effects like heatwave shimmers and the like - which now that I think about it sounds pretty powerful.

cspang1, 2019-10-29:
With projected algorithm, 2 things are absolutely necessary:

1. Scanline 0 is initialized with in-bounds x/y position coordinates in `plx_pos`, and
2. Any unused parallax array entries have their scanline index (7:0) set higher than the highest scanline (240)

cspang1, 2019-10-31:
Successfully implemented multi-line parallax scrolling!

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

Only limitation currently is that you can't have parallaxing between lines <6 scanlines apart, but this should be resolved in the next iteration.

cspang1, 2019-11-01:
This godforsaken yet 100% worth-the-effort feature has been implemented as of 78842387112f13ae35a6649054fae9641b853826. Now, every single scanline can be individually parallaxed in both the X and Y directions. I've probably spent ~12 solid man-hours this week working and reworking the algorithm to get this functional. I've been thwarted by [a fat-fingered immediate value mishap](https://forums.parallax.com/discussion/comment/1480931#Comment_1480931), by a missing `wc` effect flag, and more incredibly by[ an errant effect flag check somehow not only being left in](https://github.com/cspang1/JCAP/commit/78842387112f13ae35a6649054fae9641b853826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) after all of the past refactoring - but not even create [a completely baffling issue](https://github.com/cspang1/JCAP/commit/888871a3a573511c65c8ae4f5fdb323d330776aa) until dozens of commits later. What's even better about this one is I solved it thanks to [your extremely emphasized in red notes on flag clears caused by routine `call`s on the API wiki](https://lamestation.atlassian.net/wiki/spaces/PASM/pages/17924303/CALL) @konimaru - so thanks once again for the invaluable help :).

Closed 2019-11-01.

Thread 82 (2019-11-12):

Implement full-featured gfx sys demo

cspang1, 2019-11-12:
With all features of the graphics system now implemented:

- VGA 640x480 @ 60 Hz (rendered @ 320x240)
- Sprites + tiles
- Wide/tall sprites
- Bidirectional smooth scrolling
- Tile map wrapping
- Parallax scrolling

A demo should be created showcasing the spread of features to compare with similar embedded systems (e.g. Maccasoft P8X system, Hydra, etc.)

Addt'ly, implementing all features will verify stability of system under heavy CPU and GPU loads.

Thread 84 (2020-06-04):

Implement GPU bank switching

cspang1, 2020-06-04:
Can branch in `rx.spin`  to respond to specific message from `tx.spin`, calling a routine which swaps out sprites/tiles/tile maps from EEPROM.

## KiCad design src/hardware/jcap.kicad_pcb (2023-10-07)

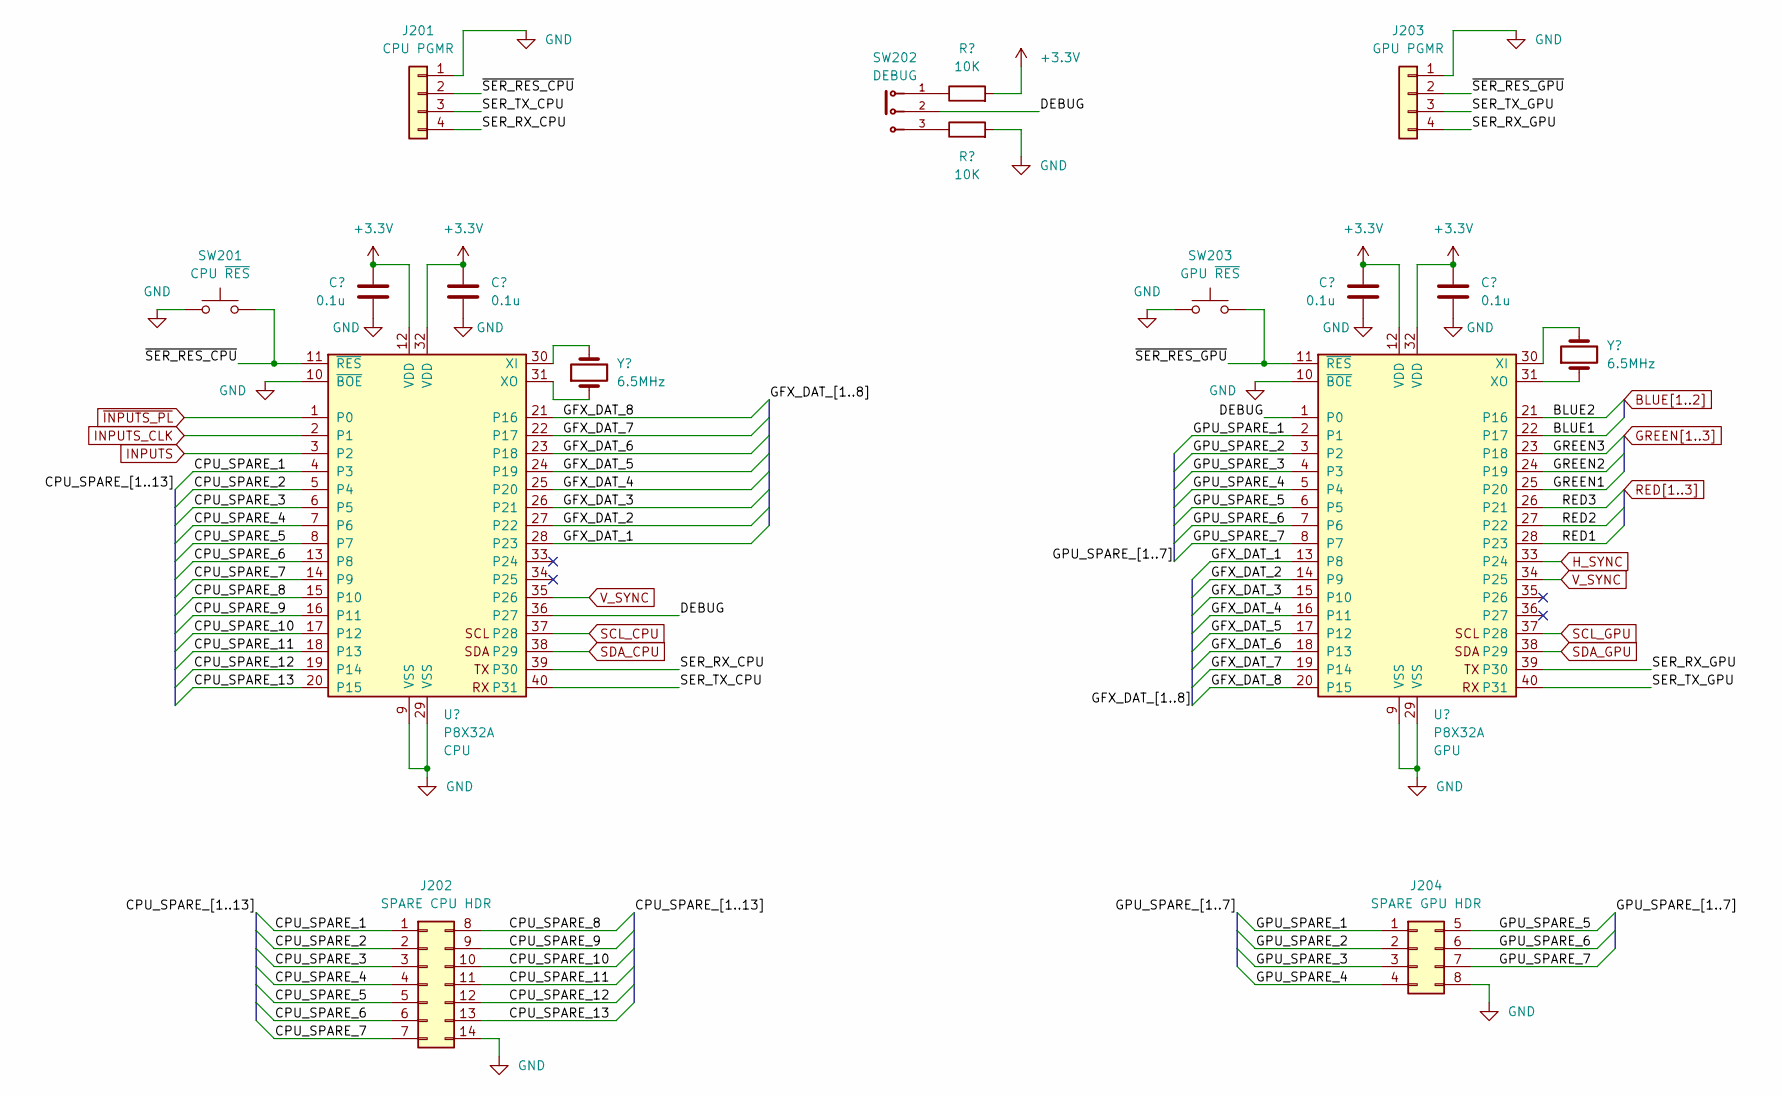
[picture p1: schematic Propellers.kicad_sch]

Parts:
C201, C202, C203, C204: 0.1u; C_Disc_D3.4mm_W2.1mm_P2.50mm; Part K104K15X7RF5TL2
J201: CPU PGMR; PinHeader_1x04_P2.54mm_Horizontal; Part K104K15X7RF5TL2
J202: SPARE CPU HDR; PinHeader_2x07_P2.54mm_Vertical; Part PH2-14-UA
J203: GPU PGMR; PinHeader_1x04_P2.54mm_Horizontal; Part K104K15X7RF5TL2
J204: SPARE GPU HDR; PinHeader_2x04_P2.54mm_Vertical; Part PH2-08-UA
R201, R202: 10K; R_Axial_DIN0207_L6.3mm_D2.5mm_P10.16mm_Horizontal; Part RNF14FTD10K0
SW201: CPU ~{RES}; SW_PUSH_6mm_H5mm; Part B3F-1002
SW202: DEBUG; SW_1825159-1; Part EG1218
SW203: GPU ~{RES}; SW_PUSH_6mm_H5mm; Part B3F-1002
U201, U202: P8X32A; DIP-40_W15.24mm_Socket; Part P8X32A-D40
Y201, Y202: 6.5MHz; Crystal_HC49-U_Vertical; Part ECS-65-20-4X

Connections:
+3.3V: C201.2, C202.2, C203.2, C204.2, R201.2, U201.12 (VDD), U201.32 (VDD), U202.12 (VDD), U202.32 (VDD); also elsewhere on the board
/Propellers/CPU_SPARE_1: J202.1, U201.4 (P3)
/Propellers/CPU_SPARE_2: J202.2, U201.5 (P4)
/Propellers/CPU_SPARE_3: J202.3, U201.6 (P5)
/Propellers/CPU_SPARE_4: J202.4, U201.7 (P6)
/Propellers/CPU_SPARE_5: J202.5, U201.8 (P7)
/Propellers/CPU_SPARE_6: J202.6, U201.13 (P8)
/Propellers/CPU_SPARE_7: J202.7, U201.14 (P9)
/Propellers/CPU_SPARE_8: J202.8, U201.15 (P10)
/Propellers/CPU_SPARE_9: J202.9, U201.16 (P11)
/Propellers/CPU_SPARE_10: J202.10, U201.17 (P12)
/Propellers/CPU_SPARE_11: J202.11, U201.18 (P13)
/Propellers/CPU_SPARE_12: J202.12, U201.19 (P14)
/Propellers/CPU_SPARE_13: J202.13, U201.20 (P15)
/Propellers/DEBUG: SW202.2, U201.36 (P27), U202.1 (P0)
/Propellers/GFX_DAT_1: U201.28 (P23), U202.13 (P8)
/Propellers/GFX_DAT_2: U201.27 (P22), U202.14 (P9)
/Propellers/GFX_DAT_3: U201.26 (P21), U202.15 (P10)
/Propellers/GFX_DAT_4: U201.25 (P20), U202.16 (P11)
/Propellers/GFX_DAT_5: U201.24 (P19), U202.17 (P12)
/Propellers/GFX_DAT_6: U201.23 (P18), U202.18 (P13)
/Propellers/GFX_DAT_7: U201.22 (P17), U202.19 (P14)
/Propellers/GFX_DAT_8: U201.21 (P16), U202.20 (P15)
/Propellers/GPU_SPARE_1: J204.1, U202.2 (P1)
/Propellers/GPU_SPARE_2: J204.2, U202.3 (P2)
/Propellers/GPU_SPARE_3: J204.3, U202.4 (P3)
/Propellers/GPU_SPARE_4: J204.4, U202.5 (P4)
/Propellers/GPU_SPARE_5: J204.5, U202.6 (P5)
/Propellers/GPU_SPARE_6: J204.6, U202.7 (P6)
/Propellers/GPU_SPARE_7: J204.7, U202.8 (P7)
/Propellers/SER_RX_CPU: J201.4, U201.39 (P30)
/Propellers/SER_RX_GPU: J203.4, U202.39 (P30)
/Propellers/SER_TX_CPU: J201.3, U201.40 (P31)
/Propellers/SER_TX_GPU: J203.3, U202.40 (P31)
/Propellers/~SER_RES_GPU: J203.2, SW203.2, U202.11 (~RES)
BLUE1: U202.22 (P17); also elsewhere on the board
BLUE2: U202.21 (P16); also elsewhere on the board
GND: C201.1, C202.1, C203.1, C204.1, J201.1, J202.14, J203.1, J204.8, R202.2, SW201.1, SW203.1, U201.9 (VSS), U201.10 (~BOE), U201.29 (VSS), U202.9 (VSS), U202.10 (~BOE), U202.29 (VSS); also elsewhere on the board
GREEN1: U202.25 (P20); also elsewhere on the board
GREEN2: U202.24 (P19); also elsewhere on the board
GREEN3: U202.23 (P18); also elsewhere on the board
H_SYNC: U202.33 (P24); also elsewhere on the board
INPUTS: U201.3 (P2); also elsewhere on the board
INPUTS_CLK: U201.2 (P1); also elsewhere on the board
unnamed: R202.1, SW202.3
unnamed: U201.30 (XI), Y201.2
unnamed: U201.31 (XO), Y201.1
unnamed: U202.30 (XI), Y202.2
unnamed: U202.31 (XO), Y202.1
RED1: U202.28 (P23); also elsewhere on the board
RED2: U202.27 (P22); also elsewhere on the board
RED3: U202.26 (P21); also elsewhere on the board
SCL_CPU: U201.37 (P28); also elsewhere on the board
SCL_GPU: U202.37 (P28); also elsewhere on the board
SDA_CPU: U201.38 (P29); also elsewhere on the board
SDA_GPU: U202.38 (P29); also elsewhere on the board
V_SYNC: U201.35 (P26), U202.34 (P25); also elsewhere on the board
~INPUTS_PL: U201.1 (P0); also elsewhere on the board

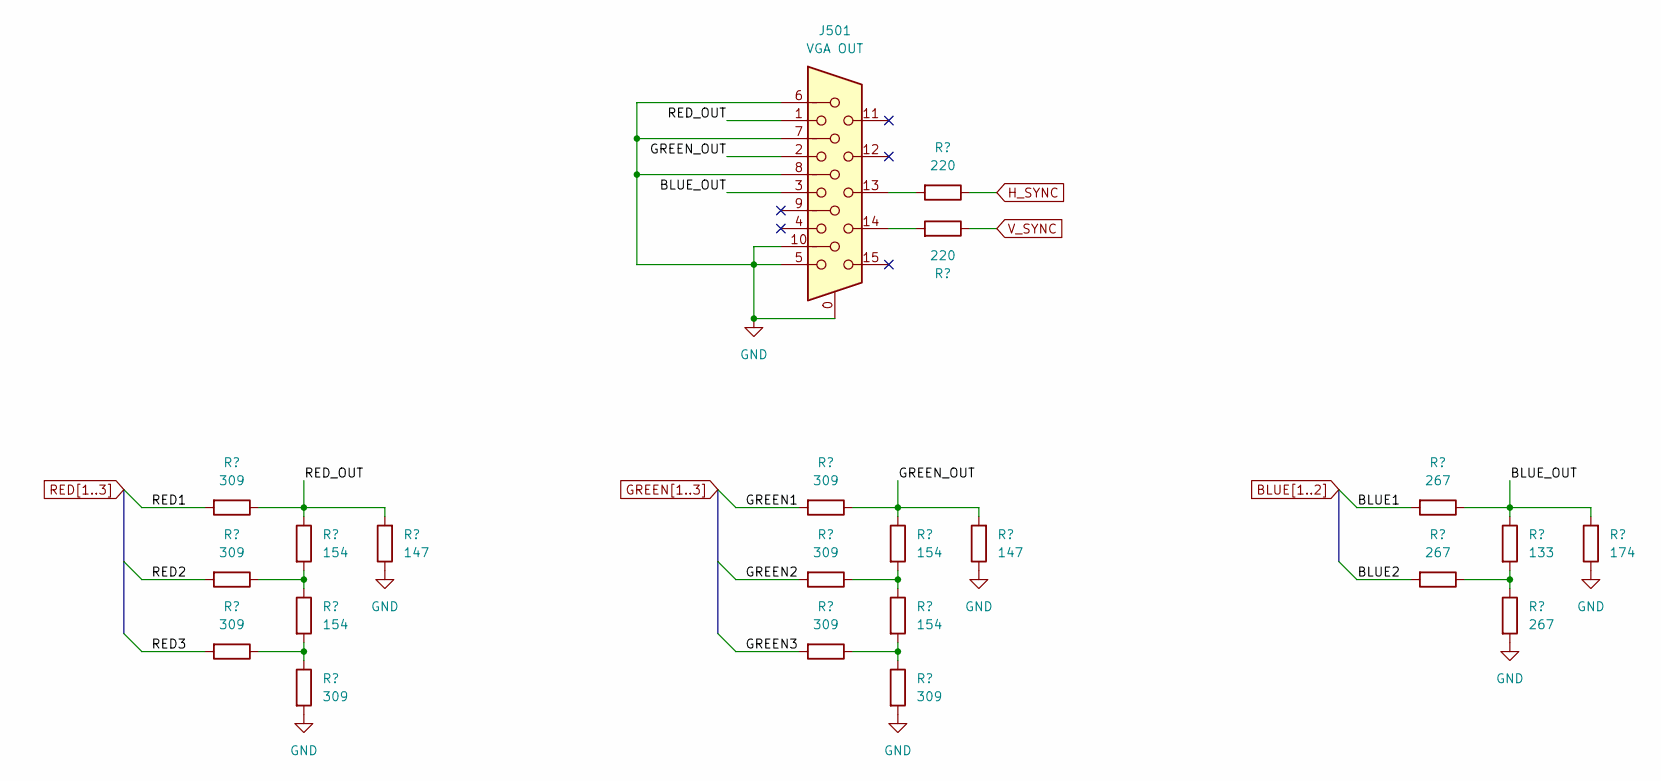
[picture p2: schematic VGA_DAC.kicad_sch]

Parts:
J501: VGA OUT; 2311763-2; Part 2311763-2
R501, R502, R503, R506, R508, R509, R510, R513: 309; R_Axial_DIN0207_L6.3mm_D2.5mm_P10.16mm_Horizontal; Part SFR16S0003090FR500
R504, R505, R511, R512: 154; R_Axial_DIN0207_L6.3mm_D2.5mm_P10.16mm_Horizontal; Part MFR-25FBF52-154R
R507, R516: 147; R_Axial_DIN0207_L6.3mm_D2.5mm_P10.16mm_Horizontal; Part MFR-25FBF52-147R
R514, R515: 220; R_Axial_DIN0207_L6.3mm_D2.5mm_P10.16mm_Horizontal; Part MFR-25FRF52-220R
R517, R518, R520: 267; R_Axial_DIN0207_L6.3mm_D2.5mm_P10.16mm_Horizontal; Part RNF14FTD267R
R519: 133; R_Axial_DIN0207_L6.3mm_D2.5mm_P10.16mm_Horizontal; Part MFR-25FBF52-133R
R521: 174; R_Axial_DIN0207_L6.3mm_D2.5mm_P10.16mm_Horizontal; Part MFR-25FRF52-174R

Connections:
/VGA_DAC/BLUE_OUT: J501.3, R517.1, R519.1, R521.2
/VGA_DAC/GREEN_OUT: J501.2, R508.1, R511.1, R516.2
/VGA_DAC/RED_OUT: J501.1, R501.1, R504.1, R507.2
BLUE1: R517.2; also elsewhere on the board
BLUE2: R518.2; also elsewhere on the board
GND: J501.0, J501.5, J501.6, J501.7, J501.8, J501.10, R506.2, R507.1, R513.2, R516.1, R520.2, R521.1; also elsewhere on the board
GREEN1: R508.2; also elsewhere on the board
GREEN2: R509.2; also elsewhere on the board
GREEN3: R510.2; also elsewhere on the board
H_SYNC: R514.1; also elsewhere on the board
unnamed: J501.13, R514.2
unnamed: J501.14, R515.2
unnamed: R502.1, R504.2, R505.1
unnamed: R503.1, R505.2, R506.1
unnamed: R509.1, R511.2, R512.1
unnamed: R510.1, R512.2, R513.1
unnamed: R518.1, R519.2, R520.1
RED1: R501.2; also elsewhere on the board
RED2: R502.2; also elsewhere on the board
RED3: R503.2; also elsewhere on the board
V_SYNC: R515.1; also elsewhere on the board

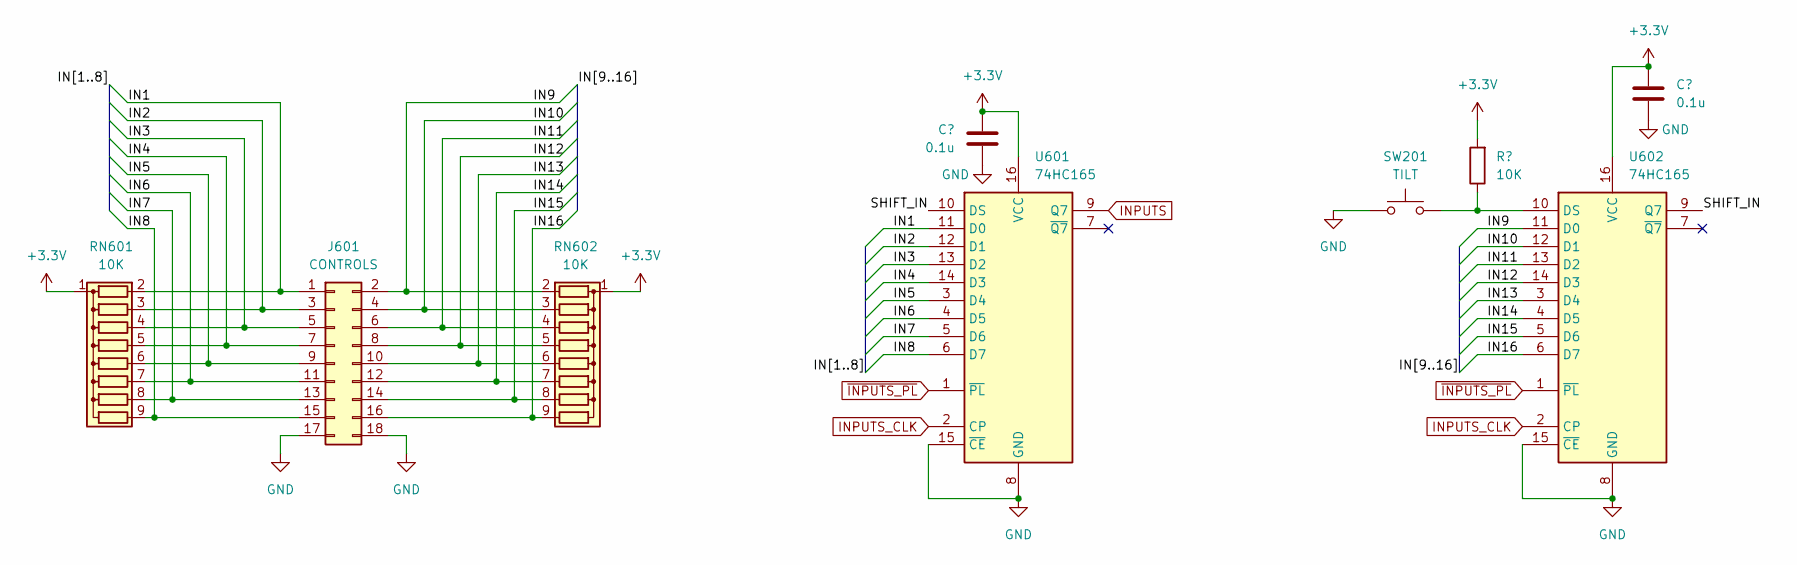
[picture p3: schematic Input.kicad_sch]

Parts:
C201: 0.1u; C_Disc_D3.4mm_W2.1mm_P2.50mm; Part K104K15X7RF5TL2
J601: CONTROLS; PinHeader_2x09_P2.54mm_Vertical; Part PH2-18-UA
R201: 10K; R_Axial_DIN0207_L6.3mm_D2.5mm_P10.16mm_Horizontal; Part RNF14FTD10K0
RN601, RN602: 10K; R_Array_SIP9; Part 4609M-101-103LF
SW201: TILT; SW_PUSH_6mm_H5mm; Part B3F-1002
U601, U602: 74HC165; DIP-16_W7.62mm_Socket; Part SN74HC165N

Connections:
+3.3V: C201.2, R201.2, RN601.1 (common), RN602.1 (common), U601.16 (VCC), U602.16 (VCC); also elsewhere on the board
/Input/IN1: J601.1, RN601.2 (R1), U601.11 (D0)
/Input/IN2: J601.3, RN601.3 (R2), U601.12 (D1)
/Input/IN3: J601.5, RN601.4 (R3), U601.13 (D2)
/Input/IN4: J601.7, RN601.5 (R4), U601.14 (D3)
/Input/IN5: J601.9, RN601.6 (R5), U601.3 (D4)
/Input/IN6: J601.11, RN601.7 (R6), U601.4 (D5)
/Input/IN7: J601.13, RN601.8 (R7), U601.5 (D6)
/Input/IN8: J601.15, RN601.9 (R8), U601.6 (D7)
/Input/IN9: J601.2, RN602.2 (R1), U602.11 (D0)
/Input/IN10: J601.4, RN602.3 (R2), U602.12 (D1)
/Input/IN11: J601.6, RN602.4 (R3), U602.13 (D2)
/Input/IN12: J601.8, RN602.5 (R4), U602.14 (D3)
/Input/IN13: J601.10, RN602.6 (R5), U602.3 (D4)
/Input/IN14: J601.12, RN602.7 (R6), U602.4 (D5)
/Input/IN15: J601.14, RN602.8 (R7), U602.5 (D6)
/Input/IN16: J601.16, RN602.9 (R8), U602.6 (D7)
/Input/SHIFT_IN: U601.10 (DS), U602.9 (Q7)
GND: C201.1, J601.17, J601.18, SW201.1, U601.8 (GND), U601.15 (~CE), U602.8 (GND), U602.15 (~CE); also elsewhere on the board
INPUTS: U601.9 (Q7); also elsewhere on the board
INPUTS_CLK: U601.2 (CP), U602.2 (CP); also elsewhere on the board
~INPUTS_PL: U601.1 (~PL), U602.1 (~PL); also elsewhere on the board

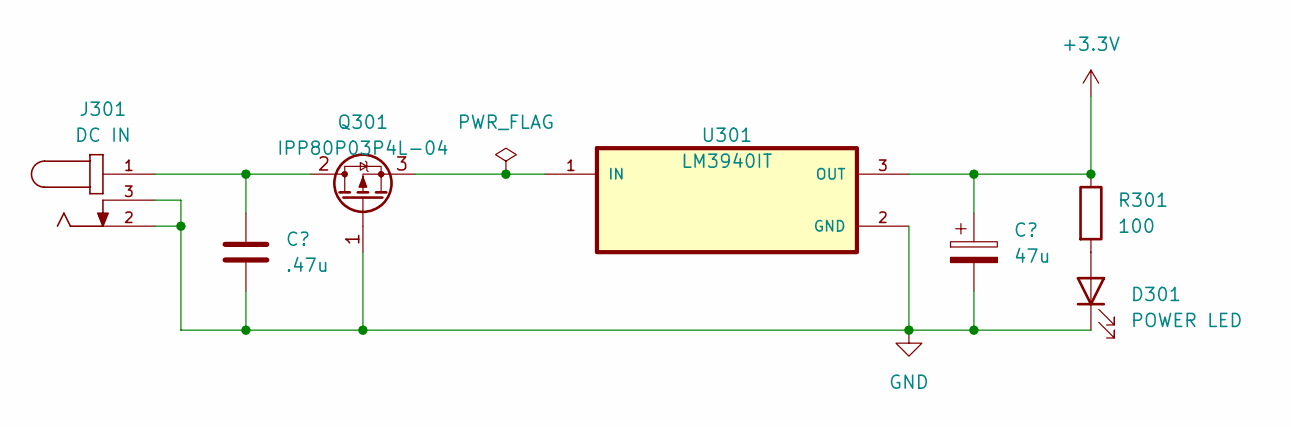
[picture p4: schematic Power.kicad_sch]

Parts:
C301: .47u; C_Disc_D3.4mm_W2.1mm_P2.50mm; Part C330C474K5R5TA
C302: 47u; C_Radial_D5.0mm_H11.0mm_P2.00mm; Part EEU-FR1J470
D301: POWER LED; LED_D5.0mm; Part HLMP-1790
J301: DC IN; CUI_PJ-202AH; Part PJ-202AH
Q301: IPP80P03P4L-04; TO-220-3_Horizontal_TabDown; Part IPP80P03P4L04AKSA2
R301: 100; R_Axial_DIN0207_L6.3mm_D2.5mm_P10.16mm_Horizontal; Part CF12JT100R
U301: LM3940IT; TO-220-3_Horizontal_TabDown; Part LM3940IT-3.3/NOPB

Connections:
+3.3V: C302.1, R301.1, U301.3 (OUT); also elsewhere on the board
GND: C301.1, C302.2, D301.1 (K), J301.2, J301.3, Q301.1 (G), U301.2 (GND); also elsewhere on the board
unnamed: D301.2 (A), R301.2
unnamed: C301.2, J301.1, Q301.2 (D)
unnamed: Q301.3 (S), U301.1 (IN)

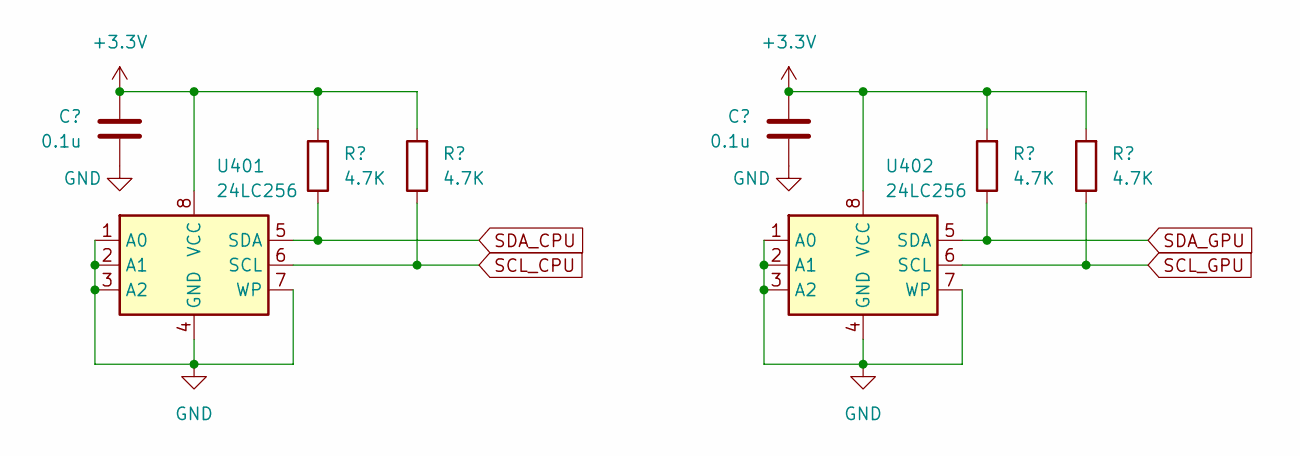
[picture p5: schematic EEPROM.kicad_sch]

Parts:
C201: 0.1u; C_Disc_D3.4mm_W2.1mm_P2.50mm; Part K104K15X7RF5TL2
R401, R402, R403, R404: 4.7K; R_Axial_DIN0207_L6.3mm_D2.5mm_P10.16mm_Horizontal; Part CF18JT4K70
U401, U402: 24LC256; DIP-8_W7.62mm_Socket; Part 24LC256-I/P

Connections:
+3.3V: C201.2, R401.2, R402.2, R403.2, R404.2, U401.8 (VCC), U402.8 (VCC); also elsewhere on the board
GND: C201.1, U401.1 (A0), U401.2 (A1), U401.3 (A2), U401.4 (GND), U401.7 (WP), U402.1 (A0), U402.2 (A1), U402.3 (A2), U402.4 (GND), U402.7 (WP); also elsewhere on the board
SCL_CPU: R402.1, U401.6 (SCL); also elsewhere on the board
SCL_GPU: R404.1, U402.6 (SCL); also elsewhere on the board
SDA_CPU: R401.1, U401.5 (SDA); also elsewhere on the board
SDA_GPU: R403.1, U402.5 (SDA); also elsewhere on the board

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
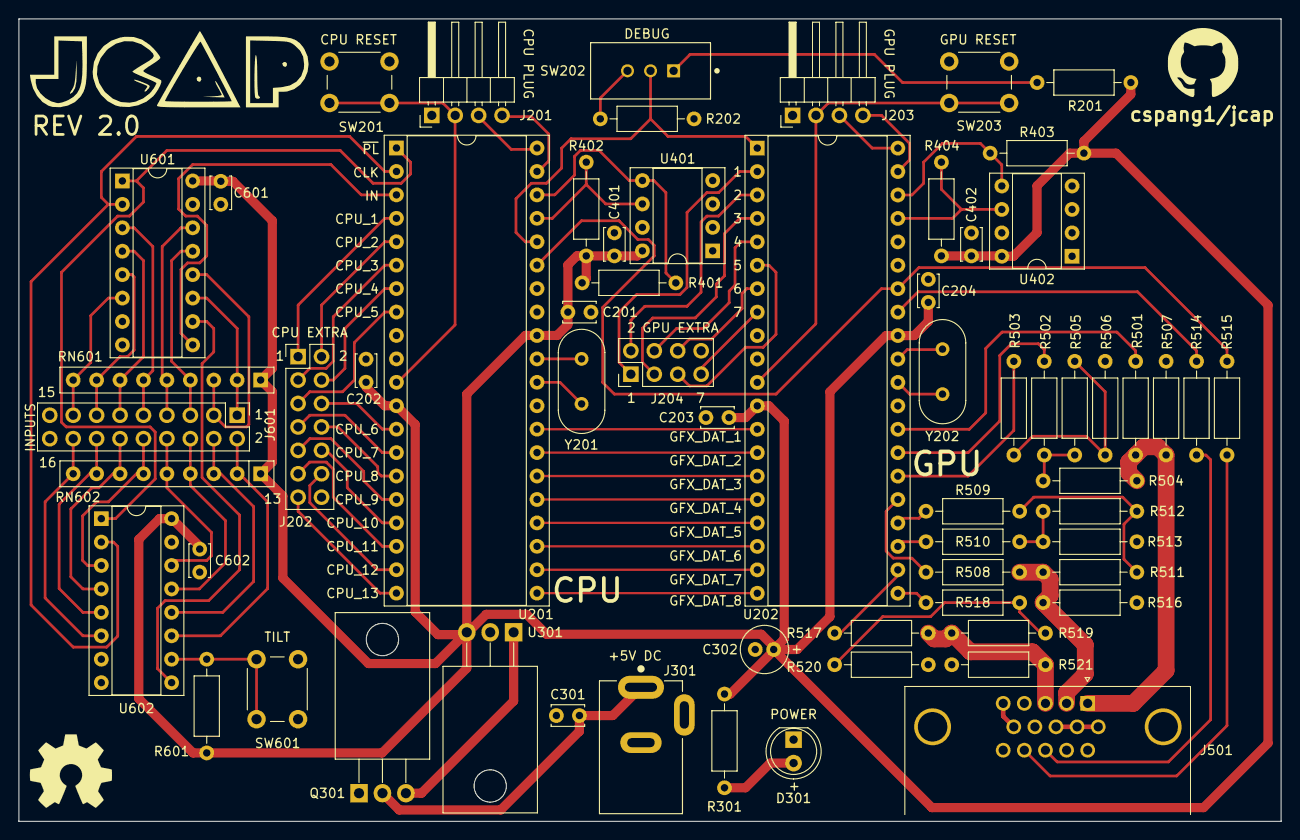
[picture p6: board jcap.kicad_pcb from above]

Board: 2 copper layers, 136.8 x 87.0 mm, 63 parts (0 on the bottom side), 91 nets.

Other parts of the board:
C401, C402, C601, C602: 0.1u; C_Disc_D3.4mm_W2.1mm_P2.50mm
R601: 10K; R_Axial_DIN0207_L6.3mm_D2.5mm_P10.16mm_Horizontal
SW601: TILT; SW_PUSH_6mm_H5mm

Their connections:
+3.3V: C401.2, C402.2, C601.2, C602.2, R601.2; also elsewhere on the board
GND: C401.1, C402.1, C601.1, C602.1, SW601.1; also elsewhere on the board

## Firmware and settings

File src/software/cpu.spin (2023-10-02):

{{
        File:     cpu.spin
        Author:   Connor Spangler
        Description: 
                  This file contains the PASM code defining a JCAP CPU
}}

CON
    ' clock settings
    _clkmode = xtal1 + pll16x     ' Standard clock mode w/ 16x PLL
    _xinfreq = 6_500_000          ' 6.5 MHz clock for x16 = 104 MHz

    ' Pin settings
    VS_PIN = 26
    TX_PIN = 23
    DEBUG_PIN = 27

    ' Test settings
    NUM_SEA_LINES = 56
    #0, UP, DOWN, LEFT, RIGHT

OBJ
    system        : "system"      ' Import system settings
    gfx_tx        : "tx"          ' Import graphics transmission system
    input         : "input"       ' Import input system
    gfx_utils     : "gfx_utils"   ' Import graphics utilities
    math_utils    : "math_utils"  ' Import math utilities
    serial        : "serial"      ' Import COM serial system

VAR
    ' Game resource pointers
    long    gfx_resources_base_     ' Register in Main RAM containing base of graphics resources

    ' Game clocks
    long    clock_

    ' TEST RESOURCE POINTERS
    long    plxvars[NUM_SEA_LINES]
    word    foxposx
    byte    foxposy
    byte    jumping
    byte    crouching
    byte    facing
    byte    jmpcnt
    byte    stillcnt
    byte    walkcnt

PUB main | time,trans,temp,x,y,z,q,elapsed,inputs
    ' Set unused pin states
    ' dira[3..7]~~
    ' dira[9..13]~~
    ' dira[16..26]~~
    ' outa[3..7]~
    ' outa[9..13]~
    ' outa[16..26]~

    dira[DEBUG_PIN]~

    ' Initialize variables
    gfx_resources_base_ := @gfx_base           ' Set graphics resources base to start of tile color palettes
    gfx_utils.setup (@plx_pos, @sprite_atts)
    clock_ := 0

    if ina[DEBUG_PIN]
        serial.init(31, 30, 19200)
        inputs := 0
        repeat while inputs == 0
            inputs := serial.rx
            if inputs <> 89
                serial.str(string("CPU"))
                ' inputs := 1
        serial.finalize

    ' Start subsystems
    input.start                             ' Start input system
    trans := constant(NEGX|TX_PIN)          ' link setup
    gfx_tx.start(@trans, VS_PIN, TX_PIN)    ' Start graphics resource transfer system
    repeat while trans

    ' Initialize sprites
    ' Fox
    foxposx := 16
    foxposy := 123
    stillcnt := 0
    walkcnt := 0
    jumping := false
    crouching := false
    facing := RIGHT
    gfx_utils.init_sprite ($4,foxposx,foxposy,$2,false,false,true,true,0)
    gfx_utils.init_sprite ($6,foxposx+16,foxposy,$2,false,false,true,true,1)
    gfx_utils.init_sprite ($8,foxposx,foxposy+16,$2,false,false,true,true,2)
    gfx_utils.init_sprite ($A,foxposx+16,foxposy+16,$2,false,false,true,true,3)

    ' Birds
    gfx_utils.init_sprite ($0,40,85,$0,false,true,false,false,4)
    gfx_utils.init_sprite ($0,56,56,$0,false,false,false,false,5)
    gfx_utils.init_sprite ($0,190,22,$0,false,true,false,false,6)
    gfx_utils.init_sprite ($0,260,70,$0,false,false,false,false,7)

    ' Setup parallaxing
    longfill(@plx_pos, 0, system#NUM_PARALLAX_REGS)
    gfx_utils.set_scr_reg_pos (50,0,0)
    x := 79
    repeat temp from 1 to NUM_SEA_LINES
        if (temp-1)//2 == 0
            plxvars[temp-1] := temp-1+148
        else
            plxvars[temp-1] := temp-1
        long[@plx_pos][temp] := x
        x += 1 
    long[@plx_pos][NUM_SEA_LINES+1] := x

    time := cnt

    ' Main game loop
    repeat
        waitcnt(time += clkfreq/60) ' Strictly for sensible sprite speed
        trans := constant(system#GFX_BUFFER_SIZE << 16) | @plx_pos{0}            ' register send request
        ifnot time//4
          long[@ti_col_pal][6] <-= 8
        repeat temp from 1 to NUM_SEA_LINES
            plxvars[temp-1] := plxvars[temp-1] + 2
            x := math_utils.sin(-plxvars[temp-1],(temp-1)//4) + 50 - (temp-1)
            if x < 0
                x += 447
            gfx_utils.set_scr_reg_hor_pos(x,temp)
        move(input.get_control_state)
        if input.get_tilt_state & 1
            longfill(@sprite_atts, 0, system#SAT_SIZE)
        animate_birds
        if jumping and jmpcnt < 25
            animate_fox_jump
            jmpcnt++
            stillcnt := 0
            walkcnt := 0
        else
            jumping := false
            jmpcnt := 0
        clock_++
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

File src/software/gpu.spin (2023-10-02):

{{
        File:     gpu.spin
        Author:   Connor Spangler
        Description: 
                  This file contains the PASM code defining a JCAP GPU
}}

CON
    ' Clock settings
    _clkmode = xtal1 + pll16x     ' Standard clock mode w/ 16x PLL
    _xinfreq = 6_500_000          ' 6.5 MHz clock for x16 = 104 MHz

    ' Pin settings
    VS_PIN = 24
    RX_PIN = 8
    DEBUG_PIN = 0

OBJ
    system        : "system"      ' Import system settings
    gfx_rx        : "rx"          ' Import graphics reception system
    vga_render    : "vga_render"  ' Import VGA render system
    vga_display   : "vga_display" ' Import VGA display system
    serial        : "serial"      ' Import COM serial system

VAR
    ' Video system pointers
    long  gfx_buffer_base_        ' Register pointing to graphics resources buffer
    long  gfx_buffer_size_        ' Size of the graphics buffer
    long  data_ready_base_        ' Register pointing to data status indicator
    long  cur_scanline_base_      ' Register pointing to current scanline being requested by the VGA Display system
    long  scanline_buff_base_     ' Register pointing to scanline buffer
    long  horizontal_position_    ' Register pointing to base of scanline parallax positions
    long  tcolor_palette_base_    ' Register pointing to base of tile color palettes
    long  scolor_palette_base_    ' Register pointing to base of sprite color palettes
    long  sprite_att_base_        ' Register pointing to base of sprite attribute table
    long  tile_map_base_          ' Register pointing to base of tile maps
    long  tile_palette_base_      ' Register pointing to base of tile palettes
    long  sprite_palette_base_    ' Register pointing to base of sprite palettes

PUB main | rx1, rx2, debug
    ' Set unused pin states
    ' dira[2..7]~~
    ' dira[9..15]~~
    ' dira[27]~~
    ' outa[2..7]~
    ' outa[9..15]~
    ' outa[27]~

    dira[DEBUG_PIN]~

    ' Initialize graphics system pointers
    gfx_buffer_base_ := @gfx_buff                                                   ' Point graphics buffer base to graphics buffer
    gfx_buffer_size_ := system#GFX_BUFFER_SIZE                                      ' Set the size of the graphics resources buffer
    cur_scanline_base_ := @cur_scanline                                             ' Point current scanline base to current scanline
    data_ready_base_ := @data_ready                                                 ' Point data ready base to data ready indicator
    scanline_buff_base_ := @scanline_buff                                           ' Point video buffer base to video buffer
    horizontal_position_ := gfx_buffer_base_                                        ' Point tile color palette base to base of tile color palettes
    tcolor_palette_base_ := horizontal_position_+system#NUM_PARALLAX_REGS*4         ' Point tile color palette base to base of tile color palettes
    scolor_palette_base_ := tcolor_palette_base_+system#NUM_TILE_COLOR_PALETTES*4*4 ' Point sprite color palette base to base of sprite color palettes
    sprite_att_base_ := scolor_palette_base_+system#NUM_SPRITE_COLOR_PALETTES*4*4   ' Point sprite attribute table base to base of sprite attribute table
    tile_map_base_ := sprite_att_base_+system#SAT_SIZE*4                            ' Point tile map base to base of tile maps
    tile_palette_base_ := @tile_palettes                                            ' Point tile palette base to base of tile palettes
    sprite_palette_base_ := @sprite_palettes                                        ' Point sprite palette base to base of sprite palettes

    ' Start subsystems
    rx1 := constant(NEGX|RX_PIN)
    rx2 := constant(system#GFX_BUFFER_SIZE << 16) | @gfx_buff

    if ina[DEBUG_PIN]
        serial.init(31, 30, 19200)
        debug := 0
        repeat while debug == 0
            debug := serial.rx
            if debug <> 89
                serial.str(string("GPU"))
                ' debug := 1
        serial.finalize

    gfx_rx.start(@rx1, VS_PIN, RX_PIN)                       ' Start video data RX driver
    repeat while rx1

    vga_display.start(@data_ready_base_)                  ' Start display driver
    vga_render.start(@data_ready_base_)                   ' Start renderers

DAT

              ' Graphics engine resources
data_ready    long      0                       ' Graphics data ready indicator
cur_scanline  long      0                       ' Current scanline being rendered
scanline_buff long      0[system#VID_BUFFER_SIZE]      ' Video buffer
gfx_buff      long      0[system#GFX_BUFFER_SIZE]      ' Graphics resources buffer

tile_palettes   file    "tiles.dat"

sprite_palettes file    "sprites.dat"

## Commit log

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2017-05-31 Added Docs subdirectory, including datasheets and manuals collected for Propeller, PASM, and 74HC165
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2017-05-31 Updated 74HC165D verilog file to fix multiple driver error. Added multiple helpful documents to Docs/Manuals/. Implemented 74HC165D verilog design into P8X32A Quartus top-level design (loading onto D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
2017-06-01 Added WaveForms workspace file for testbench. Updated input.spin to implement interaction with 74HC165. Updated top-level Propeller tdf AHDL file to properly connect 74HC165 to DE0-Nano pins. Updated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
2017-06-03 Fixed critical bug caused by improperly defining output pin bitmask. Updated WaveForms 74HC165 workspace to be more concise. Updated top.tdf to include second, daisy-chained 74HC165.
2017-06-05 Updated input.spin to poll and store to Main RAM the state of the tilt sensor.
2017-06-06 Refactored input.spin to properly store input and tilt states in Main RAM. Added "testing" function to display input and tilt states on DE0-Nano LEDs. Modified top.tdf to re-assign LED pins to Propel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
2017-06-10 Created wip/video/vga branch for developing VGA video. Added a couple DAC examples. Created vga.spin file.
2017-06-14 Tinkered with vga.spin. Added Counter PLL calculator to docs/Other. Modified VGA Waveforms workspace.
    [Counter_PLL_Calc.xlsx]
2017-06-14 Updated counter PLL calculator
    [Counter_PLL_Calc.xlsx]
2017-06-14 More tinkering with vga.spin. Updated counter PLL calc.
    [Counter_PLL_Calc.xlsx]
2017-06-15 Began adding video generation logic to vga.spin. Populated counter PLL calculator w/ 640x480 @ 60 Hz values.
    [Counter_PLL_Calc.xlsx]
2017-10-26 Started adding test code/values to develop a monochromatic 640x480 60Hz VGA routine
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2017-11-06 Added excel calculator of compatible tile dimensions to other useful docs
    [Compatible_Tile_Calc.xlsx]
2017-11-07 Updated compatible tile dimension calculator
    [Compatible_Tile_Calc.xlsx]
2017-11-07 Updated tile dimension calc
    [Compatible_Tile_Calc.xlsx]
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2017-11-13 Fixed misidentified bug w/ VGA driver start/stop via inputs
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2017-11-20 Added multicog sandbox
    [Multicog_Sandbox.xlsx]
2017-11-21 Made frustrated progress on multicog VGA driver
    [Multicog_Sandbox.xlsx]
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2017-11-22 Completed working initial version of multicog VGA driver
    [Multicog_Sandbox.xlsx]
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2018-02-14 Added document outlining solution to sprite visibility checking
    [sprite_bounds_check.xlsx]
2018-02-15 Added sprite palette offset calculation (needs verification)
    [sprite_bounds_check.xlsx]
2018-02-16 Completed basic sprite system; removed redundant documents
    [Compatible_Tile_Calc.xlsx, Counter_PLL_Calc.xlsx, Multicog_Sandbox.xlsx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]
2018-02-24 Added tilemap position variables; refactored render system variable loading; implemented explicit scanline sprite limit
    [sprite_bounds_check.xlsx]
2018-02-24 Removed sprite sizing from render routine
    [sprite_bounds_check.xlsx]
2018-05-01 Cosmetic variable name change
    [sprite_bounds_check.xlsx]
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2018-05-16 Updated scratchpad
    [scratchpad.xlsx, sprite_bounds_check.xlsx]
2018-05-18 Overhauled TX/RX routines to fix timing/pin errors
    [rx_test.spin, tx_test.spin]
2018-05-25 Incorporated graphics routines into RX; ready to implement watchdog
    [scratchpad.xlsx]
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2018-06-06 Fixed sprite tearing bug by waiting for next data buffer
    [rx_test.spin, tx_test.spin]
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2018-06-13 Revert "Experimental logic flow"
    This reverts commit f045fb5e9e0690fd27d89669bea25c4eb440f6c9.
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2018-06-26 Fixed TX refactor bug
    [cpu.spin]
2019-03-22 Implemented potential startup de-sync fix; need to verify
    [gpu.spin]
2019-05-15 Fixed GFX de-sync issue
    [cpu.spin, gpu.spin]
2019-05-17 Fixed horizontal scroll wrap
    [cpu.spin]
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2019-10-28 Began implementing vertical sprite changes
    [scratchpad.xlsx]
2019-10-28 Successfully implemented vertical sprite sizing+mirroring!
    [scratchpad.xlsx]
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2019-11-12 Fixed negative sine bug
    [cpu.spin]
2019-11-15 Fixed sprite wrapping logic; implemented animation demo
    [cpu.spin, gpu.spin, system.spin]
2019-11-17 Implemented fox animations & added compile error checking to sysload
    [cpu.spin, system.spin]
2019-11-19 Fixed folder names
    [Counter_PLL_Calc.xlsx, scratchpad.xlsx]
2023-08-30 Minor diction and syntax fixes; added system explanation
    [cpu.spin, gpu.spin, system.spin]
2023-08-31 Additional documentation overhaul
    [scratchpad.xlsx]
2023-09-05 Started KiCad project
    [jcap.kicad_pcb, jcap.kicad_sch]
2023-09-06 Started developing sheet hierarchy
    [Power.kicad_sch, Propellers.kicad_sch, jcap.kicad_sch]
2023-09-06 Continued developing JCAP schematic
    [EEPROM.kicad_sch, Power.kicad_sch, Propellers.kicad_sch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]
2023-09-06 Finalized initial schematic
    [EEPROM.kicad_sch, Input.kicad_sch, Power.kicad_sch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]
2023-09-07 Started developing PCB layout
    [EEPROM.kicad_sch, Input.kicad_sch, Power.kicad_sch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]
2023-09-07 Fixed resistors and reset PCB
    [Input.kicad_sch, Propellers.kicad_sch, jcap.kicad_pcb]
2023-09-07 Updated netclasses and PCB specs
    [EEPROM.kicad_sch, Input.kicad_sch, Power.kicad_sch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]
2023-09-07 Ready for routing
    [Power.kicad_sch, jcap.kicad_pcb]
2023-09-07 Fixed netclasses
    [Propellers.kicad_sch]
2023-09-08 Finished draft PCB
    [Propellers.kicad_sch, jcap.kicad_pcb]
2023-09-08 Fixed lib footprint 3D model refs
    [jcap.kicad_pcb]
2023-09-08 Nearly final PCB
    [jcap.kicad_pcb]
2023-09-08 Updated input header pinout
    [Input.kicad_sch, jcap.kicad_pcb]
2023-09-16 Finalized optimized board layout
    [Input.kicad_sch, Propellers.kicad_sch, jcap.kicad_pcb]
2023-09-16 Added silkscreen - review ready
    [jcap.kicad_pcb]
2023-09-17 Finalized review schematic & pcb
    [EEPROM.kicad_sch, Input.kicad_sch, Propellers.kicad_sch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]
2023-09-18 Thicc-traced VGA sig test - REVERT HERE
    [EEPROM.kicad_sch, Input.kicad_sch, Power.kicad_sch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]
2023-09-18 75 ohm DAC traces final refactor
    [jcap.kicad_pcb]
2023-09-18 Finalized review PCB #2
    [jcap.kicad_pcb]
2023-09-19 Implemented review changes - missing reverse polarity protection
    [EEPROM.kicad_sch, Power.kicad_sch, Propellers.kicad_sch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]
2023-09-22 Finalized physical layout
    [Power.kicad_sch, jcap.kicad_pcb]
2023-09-24 Finalized dev PCB for 1st run
    [Power.kicad_sch, jcap.kicad_pcb]
2023-09-25 Finalized silkscreen - now actually ready for prod
    [jcap.kicad_pcb]
2023-09-26 Finalized dev board administrivia
    [EEPROM.kicad_sch, Input.kicad_sch, Power.kicad_sch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]
2023-09-26 Refreshed README and removed docs
    [Counter_PLL_Calc.xlsx, EEPROM.kicad_sch, Input.kicad_sch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]
2023-10-03 Merged changes
    [EEPROM.kicad_sch, Input.kicad_sch, Power.kicad_sch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]
2023-10-03 Fixed sync pin mixup - Rev 2.0
    [VGA_DAC.kicad_sch, jcap.kicad_pcb]
2023-10-03 Added silkscreen idents & fixed missing gnd pin on input hdr
    [Input.kicad_sch, jcap.kicad_pcb]
2023-10-03 Added second gnd to input hdr
    [Input.kicad_sch, jcap.kicad_pcb]
2023-10-04 Added GND pins to spare headers
    [Propellers.kicad_sch, jcap.kicad_pcb]
2023-10-07 Swapped H/VSync pins
    [Propellers.kicad_sch, jcap.kicad_pcb]
2023-10-07 Updated crystal scale
    [jcap.kicad_pcb]
